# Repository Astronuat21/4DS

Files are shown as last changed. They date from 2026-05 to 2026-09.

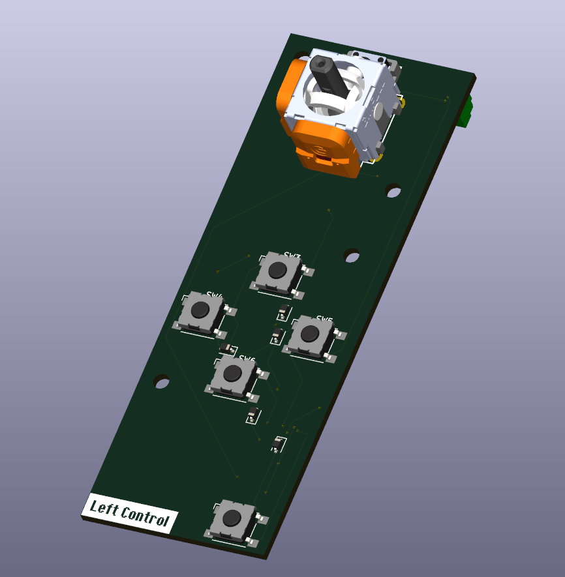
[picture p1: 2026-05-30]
Images/CTRL_L/Left_Controls_Front.png

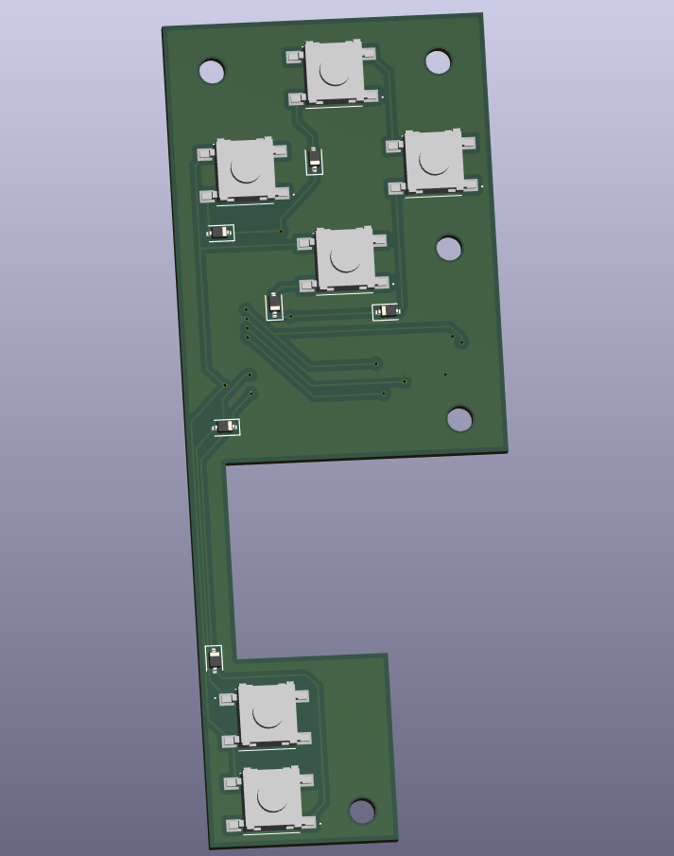
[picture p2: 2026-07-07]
Images/CTRL_R/Right_Controls_Front.png

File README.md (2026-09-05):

Hallo! Welcome to the Github Repository for the 4DS.

4DS is a solo project by Astronuat21 (me!!) aiming to make a dual screen console _akin to the Nintendo DS's_ but with stronger hardware, better battery life and specs in general. The device is also much larger than the ones you might have at home; coming in at around 19x11.5x3cm, the device is better suited for people with bigger hands who may find uncomfortability using even the stardard XL models. The hardware mostly tops the Switch, using the Lattepanda Mu SoC and it's N100 CPU, alongside 16GB of RAM and expandable Gen 3 SSD storage. If you so choose, this project should also be compatible with the upgraded N305 version (although it will be almost useless due to its higher PSU requirements).

This repository contains all the PCB files used in this project, including schematics and circuit boards. **Assuming everything works,** you should be able to reproduce the exact boards I used and reprint them for yourself. Also included are all the 3D files used in 3D printing or other purposes as well as some *outdated -_-* images to look at. They can be found in **/3D Models** and **/Images** respectively. You will also need some of the additional programs included for things like the RP2354 Microcontroller, alongside some other helpful scripts, which can be found in **/Programs**.

I built this to challenge myself to make a console that I would be proud to daily drive. My 2DS XL is great, but it definitely can't play my Steam library, and while I _can_ fit a Switch in some pockets, it dosen't quite have the extensive game library (for what I actually play). Unlike the _New (or not really)_ DS, which can play NES, SNES, GB/GBA, DS, and 3DS games as well as N64 and Gamecube to some extent. The Switch needs Nintendo Online for that as far as I know, and I HATE SUBSCRIPTIONS (Also its not even all the games). So thats where I've ended up now, with the great opportunity to flex superior intellect on some friends.

I may to make a sort of v2 version of this, there are quite a few fundemental issues with the design that cant really be fixed without starting over completely. I wouldn't really bother with that unless I find a way to make huge changes, like an insane side reduction, or adding a dGPU. I would probably make that a seperate repository, but it dosen't matter for now since I have other project ideas I want to do next.

If you intend to use this repository for any reason, **PLEASE CREDIT ME!!** I am happy to have others use this project as a reference or recreate what I have built, you can contact me with whatever you make, I would be honored. In the future, a _full-ish_ guide will be provided so that you can build your own 4DS if you'd like, but hopefully the repository is clear enough that you can do it on your own.

`DISCLAIMER: The 4DS and all its files is under the AGPL-3.0 license. I'm therefore technically allowing this repository to used for things like commercial purposes, but trust me, you really don't want to start using this repo just all on your own like that. My warning to you is that many decisions made here were done from extensive research and considerations from dozens of specifications and datasheets, some areas of this design are much more sensitive than expected, and some areas are not. I am happy to clarify certain things, but depending on what you hope to use this for, I may not give my time to help you if I do not support it. Dont expect me to help you out if your goal is to throw it with some AI Slop. I'm giving this warning not because you must consult me, but if you choose not to...`

**Find someone to wish you good luck. You're going to need it.**

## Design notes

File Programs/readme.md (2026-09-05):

Welcome to the _Programs_ Folder!

This folder is for programs, I guess. Not much to say for now since, I haven't done any coding yet!

also, isn't it interesting that github says my repo is like 91.7% Powershell? I wish it included stuff like kicad_ files, but I guess its not a programming language. whatevever -_-

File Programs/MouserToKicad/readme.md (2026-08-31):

Welcome to the _Programs_ Folder!

This folder is dedicated to a little powershell script I made *(sorry linux users)*. Its a basic utility that takes the zip folder download provided by Mouser (Or anything else that uses SamacSys, really) and puts it in an easier format to import with Kicad. 

To use it, you just have to input the name of the zip folder **(WITHOUT THE LIB_ PREFIX!)** and the script does the rest. Its not a perfect script though:

1. It assums the folder is in "D:\Downloads". You'll have to modify the $Downloads value to fit your needs. Windows comes with a PowerShell IDE, so you can change it via Right Click -> Edit
2. My Powershell is borked somehow and dosent like to run the .ps1 files properly. Ive thus included a .bat file that will run it properly, _just keep them in the same folder, aight?_

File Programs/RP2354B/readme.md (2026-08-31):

Welcome to the _Programs_ Folder!

This section is for configuration the RP2354B, the onboard microcontroller which handles USB Input, LED Peripherals, ADC Inputs and other I2C tasks. Further instructions will be given once the setup is finalized.

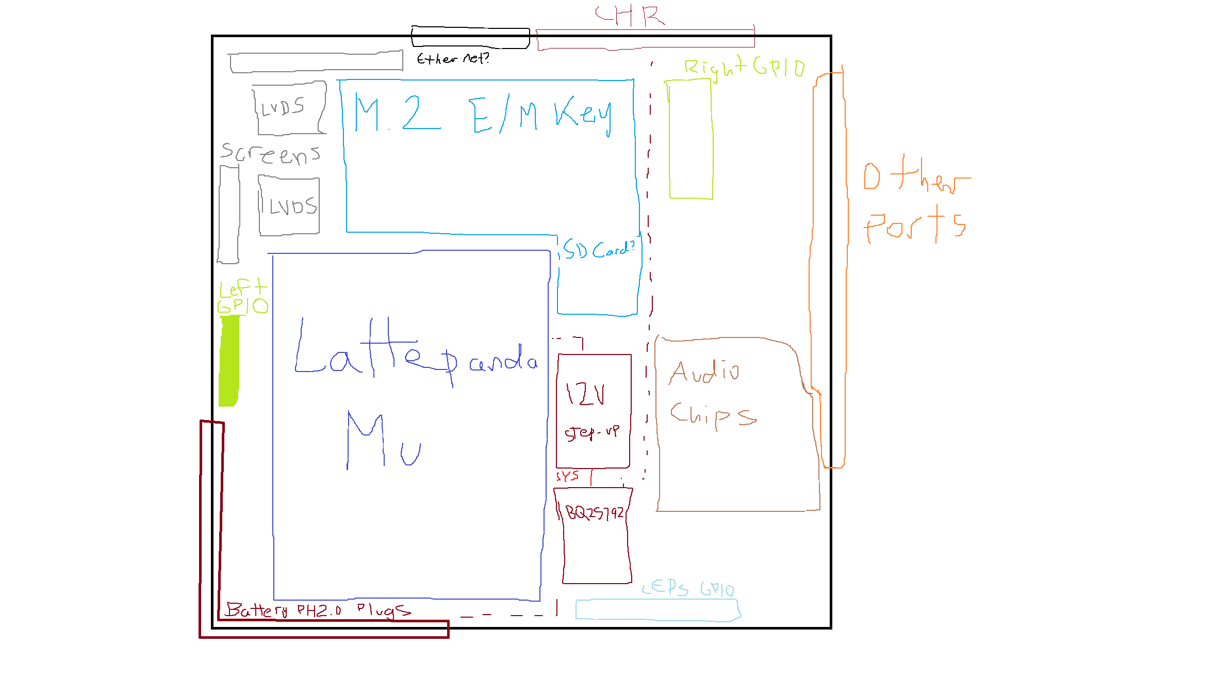
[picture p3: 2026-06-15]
Images/Motherboard/4DSMainboardConcept.png

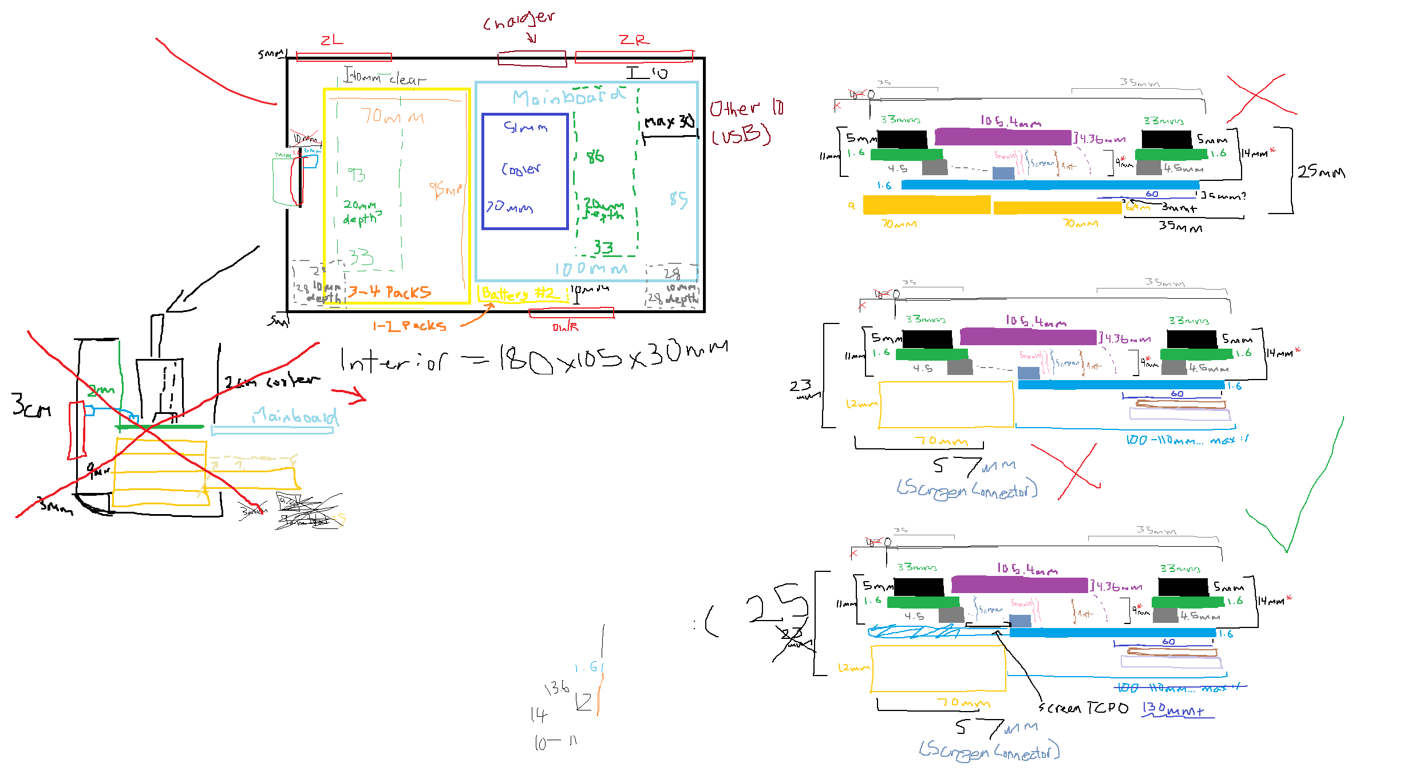
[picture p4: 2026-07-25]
Images/Other/4DS Concept Art.png

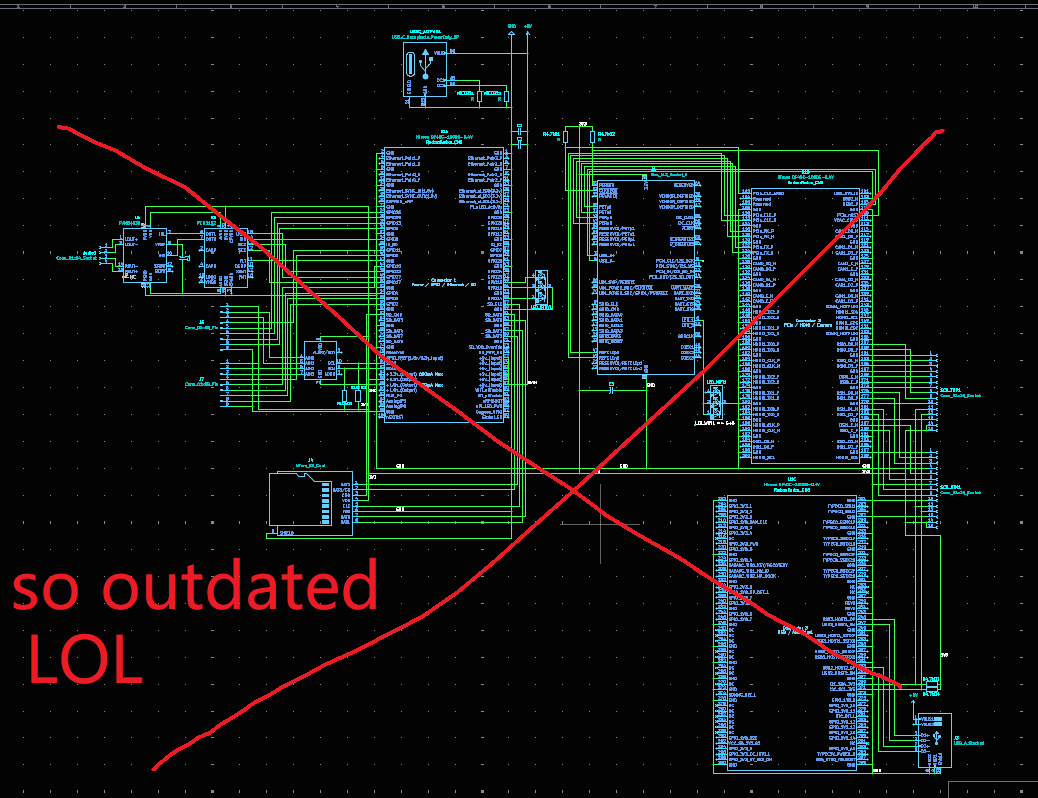
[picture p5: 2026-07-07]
Images/Motherboard/Schematic_05_11_26.png

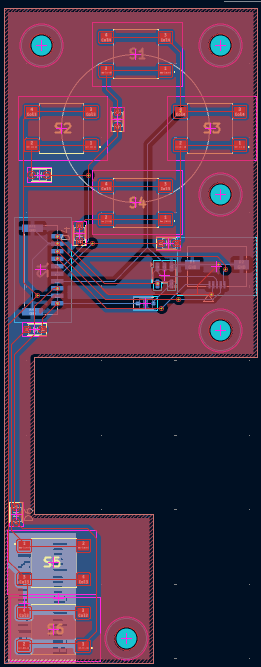
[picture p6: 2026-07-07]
Images/CTRL_R/Right_Controls_PCB.png

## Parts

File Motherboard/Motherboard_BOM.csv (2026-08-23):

Reference | Value | Footprint | Specifications (For Resistors/Capacitors) | MPN | Manufacturer
J78 | Speaker_L | Connector_Molex:Molex_PicoBlade_53047-0210_1x02_P1.25mm_Vertical | N/A | 0530470210
J79 | Speaker_R | Connector_Molex:Molex_PicoBlade_53047-0210_1x02_P1.25mm_Vertical | N/A | 0530470210
J24 | 200485-0710 | 2004850710 | N/A | 2004850710
J83 | 2004850740 | 200485-0740:CON_2004850740 | N/A | 2004850740
J90 | 2004850740 | CON_2004850740 | N/A | 2004850740
J91 | HDMI_A_1.4 | Connector_Video:HDMI_A_Molex_208658-1001_Horizontal | N/A | 2086581001
J52 | 503480-0800 | 503480-0800:5034800800 | N/A | 5034800800
J50,J51 | 5034801400 | 5034801400:5034801400 | N/A | 5034801400
L80,L83,L84 | 74438336010HT | 74438336010HT:74438336010HT | N/A | 74438336010HT
L85 | 74438336022HT | 74438336022HT:74438336022HT | N/A | 74438336022HT
F1 | 6V/50mA | Fuse:Fuse_0603_1608Metric | N/A | 0603L005/6AR
TH78 | 10k/1% | A_HDJ_Library:R_0603_1608Metric | N/A | 103AT-2
D4,D5,D6,D17,D34 | 1N5819WS | A_HDJ_Library:D_SOD-323 | N/A | 1N5819WS
Q80,Q81 | 2N7002 | Package_TO_SOT_SMD:SOT-23 | N/A | 2N7002
Y1,Y2 | ABM8-272-T3 | Crystal:Crystal_SMD_3225-4Pin_3.2x2.5mm | N/A | ABM8-272-T3
Y81,Y82 | Crystal_GND24 | A_HDJ_Library:Crystal_SMD_3225-4Pin_3.2x2.5mm | N/A | ABM8-28.63636MHZ-B2-T
A2 | LattePanda_Mu | Module_LattePanda:LattePanda_Module_H8.0mm_Horizontal |  | ADDR0207-P001A | LOTES
U96,U99 | ADV7611 | Package_QFP:LQFP-64-1EP_10x10mm_P0.5mm_EP5x5mm | N/A | ADV7611BSWZ-P-RL
C3,C4 | 15pF | Capacitor_SMD:C_0402_1005Metric | 15pF 0402 Ceramic 20% 16V X5R | any/open | any/open
C8,C9,C12,C13,C14,C15,C16,C17,C18,C20,C21 | 100nF | Capacitor_SMD:C_0402_1005Metric | 100nF 0402 Ceramic 20% 10V X5R | any/open | any/open
C10,C11,C19,C22 | 4.7uF | Capacitor_SMD:C_0402_1005Metric | 4.7uF 0402 Ceramic 20% 10V X5R | any/open | any/open
C25,C26,C27,C30,C31,C52,C54,C58,C60 | 100nF/50V | A_HDJ_Library:C_0402_1005Metric | 100nF 0402 Ceramic 20% 50V X5R | any/open | any/open
C49,C50,C55,C56 | 220nF/50V | A_HDJ_Library:C_0402_1005Metric | 220nF 0402 Ceramic 20% 50V X5R | any/open | any/open
C51,C53,C57,C59,C90,C110,C111,C112,C113,C114,C115,C116,C117,C121,C122,C123,C124,C125,C126,C127,C128,C129,C130,C140,C141,C142,C144,C145 | 10uF/10V | A_HDJ_Library:C_0402_1005Metric | 10uF 0402 Ceramic 20% 10V X5R | any/open | any/open
C61,C66 | 1uF/16V | A_HDJ_Library:C_0402_1005Metric | 1uF 0402 Ceramic 20% 16V X5R | any/open | any/open
C63,C86 | 22uF/10V | A_HDJ_Library:C_0603_1608Metric | 22uF 0603 Ceramic 20% 10V X5R | any/open | any/open
C87 | 1nF/50V | A_HDJ_Library:C_0402_1005Metric | 1nF 0402 Ceramic 10% 50V X5R | any/open | any/open
C92 | 0.1uF/25V | A_HDJ_Library:C_0603_1608Metric | 0.1uF 0603 Ceramic 20% 25V X5R | any/open | any/open
C93,C97 | 47nF/10V | A_HDJ_Library:C_0603_1608Metric | 47nF 0603 Ceramic 10% 10V X5R | any/open | any/open
C94 | 4.7uF/10V | A_HDJ_Library:C_0603_1608Metric | 4.7uF 0603 Ceramic 20% 10V X5R | any/open | any/open
C96,C153 | 10uF/10V | A_HDJ_Library:C_0603_1608Metric | 10uF 0603 Ceramic 20% 10V X5R | any/open | any/open
C100,C105,C133,C134,C135 | 10uF/25V | A_HDJ_Library:C_0603_1608Metric | 10uF 0603 Ceramic 20% 25V X5R | any/open | any/open
C101,C106 | 10uF | A_HDJ_Library:C_0603_1608Metric | 10uF 0603 Ceramic 20% 6.3V X5R | any/open | any/open
C107 | 10uF | Capacitor_SMD:C_0805_2012Metric | 10uF 0805 Ceramic 20% 16V X5R | any/open | any/open
C118,C146 | 100uF | A_HDJ_Library:C_0603_1608Metric | 100uF 0603 Ceramic 20% 10V X5R | any/open | any/open
C119,C120,C137,C147,C148,C151 | 1uF | A_HDJ_Library:C_0603_1608Metric | 1uF 0603 Ceramic 20% 10V X5R | any/open | any/open
C138 | 0.47uF | A_HDJ_Library:C_0603_1608Metric | 0.47uF 0603 Ceramic 20% 10V X5R | any/open | any/open
C150 | 10uF | A_HDJ_Library:C_0603_1608Metric | 10uF 0603 Ceramic 20% 10V X5R | any/open | any/open
C152 | 2.2uF/25V | A_HDJ_Library:C_0603_1608Metric | 2.2uF 0603 Ceramic 10% 25V X5R | any/open | any/open
C159 | 0.1uF | A_HDJ_Library:C_0603_1608Metric | 0.1uF 0603 Ceramic 20% 25V X5R | any/open | any/open
C160,C161 | 0.022uF | A_HDJ_Library:C_0603_1608Metric | 0.022uF 0603 Ceramic 20% 10V X5R | any/open | any/open
C164,C177 | 10uF | A_HDJ_Library:C_0402_1005Metric | 10uF 0402 Ceramic 20% 10V X5R | any/open | any/open
C165,C166,C176,C179 | 1uF | A_HDJ_Library:C_0402_1005Metric | 1uF 0402 Ceramic 20% 10V X5R | any/open | any/open
C167,C168,C183 | 1.2nF | A_HDJ_Library:C_0402_1005Metric | 1.2nF 0402 Ceramic 20% 50V X7R | any/open | any/open
C169 | 220nF | A_HDJ_Library:C_0402_1005Metric | 220nF 0402 Ceramic 20% 10V X5R | any/open | any/open
C170 | 10uF | A_HDJ_Library:C_0402_1005Metric | 10nF 0402 Ceramic 20% 6.3V X5R | any/open | any/open
C171 | 100nF | A_HDJ_Library:C_0603_1608Metric | 100nF 0603 Ceramic 20% 6.3V X7R | any/open | any/open
C172 | 2.2uF | A_HDJ_Library:C_0603_1608Metric | 2.2uF 0603 Ceramic 20% 10V X7R | any/open | any/open
C173 | 39nF | A_HDJ_Library:C_0402_1005Metric | 39nF 0402 Ceramic 20% 10V X5R | any/open | any/open
C174 | 91pF | A_HDJ_Library:C_0402_1005Metric | 91pF 0402 Ceramic 20% 50V C0G/NP0 | any/open | any/open
C175,C178 | 10nF | A_HDJ_Library:C_0402_1005Metric | 10nF 0402 Ceramic 20% 16V X5R | any/open | any/open
C180,C181,C182 | 47uF | Capacitor_SMD:C_0805_2012Metric | 47uF 0805 Ceramic 20% 16V X7R | any/open | any/open
R3,R12,R13,R16,R37,R47 | 1K/1% | A_HDJ_Library:R_0402_1005Metric | 1k 1% 63mW 0402 | any/open
R4,R18,R19,R20,R21,R34,R35,R36,R49,R92,R100,R101,R109,R110,R111,R115 | 10K/1% | A_HDJ_Library:R_0402_1005Metric | 10k 1% 63mW 0402 | any/open
R14,R15 | 27R | A_HDJ_Library:R_0402_1005Metric | 27R 1% 63mW 0402 | any/open
R17 | 33R/1% | A_HDJ_Library:R_0402_1005Metric | 33R 1% 63mW 0402 | any/open
R27,R29,R32,R33,R165,R180,R195 | 0R/1% | A_HDJ_Library:R_0402_1005Metric | 0R 1% 0402 | any/open
R30,R52,R53,R170,R185,R200 | 2.2K/1% | A_HDJ_Library:R_0402_1005Metric | 2.2k 1% 63mW 0402 | any/open
R43 | 6.8K/1% | A_HDJ_Library:R_0402_1005Metric | 6.8k 1% 63mW 0402 | any/open
R46,R48 | 100R/1% | A_HDJ_Library:R_0402_1005Metric | 100R 1% 63mW 0402 | any/open
R51,R80,R134,R138,R144 | 100K/1% | A_HDJ_Library:R_0402_1005Metric | 100k 1% 63mW 0402 | any/open
R76 | 100R/1% | Resistor_SMD:R_1206_3216Metric | 100R 1% 250mW 1206 | any/open
R77 | 4.7K/1% | A_HDJ_Library:R_0402_1005Metric | 4.7k 1% 63mW 0402 | any/open
R81,R82,R83,R164,R174,R177,R178,R179,R189,R192,R193,R194,R204,R207,R208 | 21.5K/1% | A_HDJ_Library:R_0402_1005Metric | 21.5k 1% 63mW 0402 | any/open
R84,R119 | 150R/1% | Resistor_SMD:R_0402_1005Metric | 150R 1% 63mW 0402 | any/open
R85,R86 | 10K/1% | Resistor_SMD:R_0402_1005Metric | 10k 1% 63mW 0402 | any/open
R89,R90 | 5.1K/1% | A_HDJ_Library:R_0402_1005Metric | 5.1k 1% 63mW 0402 | any/open
R91 | 10K/1% | A_HDJ_Library:R_0603_1608Metric | 10k 1% 100mW 0603 | any/open
R93 | 0.010R/1% | Resistor_SMD:R_2512_6332Metric | 0.01R 1% 3W 2512 | any/open
R94,R95 | 22R/1% | A_HDJ_Library:R_0603_1608Metric | 22R 1% 100mW 0603 | any/open
R97,R98,R104 | 470R/1% | A_HDJ_Library:R_0402_1005Metric | 470R 1% 63mW 0402 | any/open
R102,R106 | 16R/1% | A_HDJ_Library:R_0805_2012Metric | 16R 1% 125mW 0805 | any/open
R103,R105 | 330R/1% | A_HDJ_Library:R_0805_2012Metric | 330R 1% 125mW 0805 | any/open
R107 | 1.5k/1% | A_HDJ_Library:R_0805_2012Metric | 1.5k 1% 125mW 0805 | any/open
R108 | 1M/1% | A_HDJ_Library:R_0603_1608Metric | 1M 1% 100mW 0603 | any/open
R112 | 2R/1% | A_HDJ_Library:R_0805_2012Metric | 2R 1% 125mW 0805 | any/open
R113,R114 | 127K/1% | A_HDJ_Library:R_0402_1005Metric | 127k 1% 63mW 0402 | any/open
R116 | 100k/1% | A_HDJ_Library:R_0402_1005Metric | 100k 1% 63mW 0402 | any/open
R117 | 5.24k/1% | A_HDJ_Library:R_0402_1005Metric | 5.24k 1% 63mW 0402 | any/open
R118 | 30k/1% | A_HDJ_Library:R_0402_1005Metric | 30k 1% 63mW 0402 | any/open
R120 | 5.1R/1% | A_HDJ_Library:R_0402_1005Metric | 5.1R 1% 63mW 0402 | any/open
R121,R122,R127,R128 | 910k/1% | A_HDJ_Library:R_0402_1005Metric | 910k 1% 63mW 0402 | any/open
R123,R126 | 5k/1% | A_HDJ_Library:R_0402_1005Metric | 5k 1% 63mW 0402 | any/open
R124,R125 | 90k/1% | A_HDJ_Library:R_0402_1005Metric | 90k 1% 63mW 0402 | any/open
R129 | 10R/1% | A_HDJ_Library:R_0402_1005Metric | 10R 1% 63mW 0402 | any/open
R130,R131,R132,R133 | 47R/1% | Resistor_SMD:R_0402_1005Metric | 47R 1% 63mW 0402 | any/open
R135 | 21K/1% | A_HDJ_Library:R_0402_1005Metric | 21k 1% 63mW 0402 | any/open
R139 | 249K/1% | A_HDJ_Library:R_0402_1005Metric | 249k 1% 63mW 0402 | any/open
R145 | 76.8k/1% | A_HDJ_Library:R_0402_1005Metric | 76.8k 1% 63mW 0402 | any/open
R166,R167,R168,R169,R172,R173,R175,R176,R181,R182,R183,R184,R187,R188,R190,R191,R196,R197,R198,R199,R202,R203,R205,R206 | 56K/1% | A_HDJ_Library:R_0402_1005Metric | 56k 1% 63mW 0402 | any/open
Q11,Q23,Q29 | AO3407 | Package_TO_SOT_SMD:SOT-23 | N/A | AO3407
L5 | 3.3uH | Inductor_SMD:L_0603_1608Metric | N/A | AOTA-B201610S3R3-101-T | ABRACON
J15 | Bus_M.2_Socket_M | A_HDJ_Library:PCIe_M.2_Connectors_P=0.5mm_H=4.2mm_KeyM | N/A | APCI0107-P001A | Lian Xin Technology
J16 | Bus_M.2_Socket_E | A_HDJ_Library:PCIe_M.2_Connectors_P=0.5mm_H=4.2mm_KeyE | N/A | APCI0108-P001A | Lian Xin Technology
J85 | JST_XHP2_Battery1 | Connector_JST:JST_XH_B2B-XH-A_1x02_P2.50mm_Vertical | N/A | B2B-XH-A
J86 | JST_XHP2_Battery2 | Connector_JST:JST_XH_B2B-XH-A_1x02_P2.50mm_Vertical | N/A | B2B-XH-A
J87 | JST_XHP2_Battery3 | Connector_JST:JST_XH_B2B-XH-A_1x02_P2.50mm_Vertical | N/A | B2B-XH-A
J88 | JST_XHP2_Battery4 | Connector_JST:JST_XH_B2B-XH-A_1x02_P2.50mm_Vertical | N/A | B2B-XH-A
J89 | JST_XHP2_Battery5 | Connector_JST:JST_XH_B2B-XH-A_1x02_P2.50mm_Vertical | N/A | B2B-XH-A
D24 | 3V3 Izt=5mA | A_HDJ_Library:D_SOD-323 | N/A | B5819WS-TP
SW80,SW81 | SW_Push | Button_Switch_SMD:SW_SPST_B3U-1000P | N/A | B3U-1000P
U79 | BQ25798 | Package_DFN_QFN:Texas_RQM0029A_VQFN-29_4x4mm_P0.4mm | N/A | BQ25798RQMR
U82 | BQ27441DRZT-G1A | Package_SON:Texas_S-PDSO-N12 | N/A | BQ27441DRZT-G1A
BT2 | Battery_Cell | A_HDJ_Library:Battery_Holder_CR1220_S8411-45R |  | BS-12-B3AA003 | MYOUNG
SW82 | SW_Nidec_CAS-120A1 | Button_Switch_SMD:Nidec_Copal_CAS-120A | N/A | CAS-120A
U14 | CH224K | A_HDJ_Library:ESSOP-10-1EP_3.9x5mm_P1.0mm_EP3.2x2.3 | N/A | CH224K
R136,R137,R140,R143 | 40.2K/1% | A_HDJ_Library:R_0402_1005Metric | 40.2k 1% 63mW 0402 | CRCW040240K2FKED | Vishay-Dale
R142 | 48.7k/1% | A_HDJ_Library:R_0402_1005Metric | 48.7k 1% 63mW 0402 | CRCW040248K7FKED
R141 | 681k/1% | A_HDJ_Library:R_0402_1005Metric | 681k 1% 63mW 0402 | CRCW0402681KFKED
U89,U90,U91,U92,U97,U98 | D3V3XA4B10LP | Package_DFN_QFN:Diodes_UDFN-10_1x2.5mm_P0.5mm | N/A | D3V3XA4B10LP-7
D7,D8,D10,D11,D15,D16,D21,D33 | ESD5V0B03 | A_HDJ_Library:D_0402_1005Metric | N/A | ESD5V0B03-1006
U3,U9,U12 | ULC0524P | A_HDJ_Library:Diodes_UDFN-10_1.0x2.5mm_P0.5mm | N/A | ESDULC0524P5-TP
J84 | FFC2A33-08-T-R | FFC2A33-08-T-R:FFC2A3308TR | N/A | FFC2A33-08-T-R
C154,C155,C156,C157 | 22uF/25V | Capacitor_SMD:C_1210_3225Metric | 22uF 1210 Ceramic 20% 25V X7R | GRM32ER61E226KE15L | any/open
J81,J94 | GSB311A41EU | GSB311A41EU:GSB311A41EU | N/A | GSB311A41EU
Q12,Q24,Q25,Q26,Q27,Q28,Q30,Q31,Q32 | HM7533HBPR | Package_TO_SOT_SMD:SOT-89-3 | N/A | HM7533HBPR
L87,L88 | LQH32CN220K23L | LQH32CN220K23L:LQH32DN100K23L | N/A | LQH32CN220K23L
C139,C143 | 22uF/4V | Capacitor_SMD:C_0805_2012Metric | 22uF 0805 Ceramic 20% 4V X5R | MCASA21GAB5226MTNA01 | any/open
C149 | 22uF | Capacitor_SMD:C_0805_2012Metric | 22uF 0805 Ceramic 20% 10V X5R | MCASA21GAB5226MTNA01 | any/open
TP2,TP10 | TestPoint | A_HDJ_Library:TestPoint_Pad_D1.5mm | N/A | N/A
U80,U85 | PAM2841G | Package_DFN_QFN:DFN-8-1EP_2x2mm_P0.5mm_EP0.86x1.55mm | N/A | PAM2841GR
U84 | PAM8403D | Package_SO:SOIC-16_3.9x9.9mm_P1.27mm | N/A | PAM8403DR-H
IC78 | PCM2704CDBR | PCM2704CDBR:SOP65P780X200-28N | N/A | PCM2704CDBR
D12,D13,D14 | PESD24VS1UL-N | A_HDJ_Library:D_0402_1005Metric | N/A | PESD24VS1UL-N
J5 | SM03B-SRSS-TB | Connector_JST:JST_SH_SM03B-SRSS-TB_1x03-1MP_P1.00mm_Horizontal | N/A | SM03B-SRSS-TB
U88 | RP2354B | Package_DFN_QFN:QFN-80-1EP_10x10mm_P0.4mm_EP3.4x3.4mm | N/A | SC1512-A4
F4,F6 | 6V/2A | A_HDJ_Library:Fuse_0805_2012Metric | N/A | SMD0805B110TF
H7,H8 | MountingHole_M2.0 | A_HDJ_Library:MountingHole_3mm_M2_Pad_TopOnly | N/A | SMTWEM225STR
H9,H10 | MountingHole_Pad | A_HDJ_Library:MountingHole_3mm_M2_Pad_TopOnly | N/A | SMTWEM225STR
D18,D19,D20,D23,D28,D29,D30 | SS54 | A_HDJ_Library:D_SMA | N/A | SS54
IC82 | TPS61288LRQQR | PTPS61288RQQR | N/A | TPS61288LRQQR
IC81,IC83,IC84 | TPS62903RPJR | TPS62903RPJR:TPS62903RPJR | N/A | TPS62903RPJR
IC79 | TS3DV621RUAR | QFN50P350X900X80-43N-D | N/A | TS3DV621RUAR
J80 | USB_C_Receptacle_USB2.0_16P | Connector_USB:USB_C_Receptacle_GCT_USB4105-xx-A_16P_TopMnt_Horizontal | N/A | USB4105-GF-A
L79 | XAL8080-222MEB | XAL8080-222MED:XAL8080222MED | N/A | XAL8080-222MEB
D9,D22 | LED_G | A_HDJ_Library:LED_0603_1608Metric | N/A | XL-1608UGC-04

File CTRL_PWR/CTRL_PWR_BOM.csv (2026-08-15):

Reference | Qty | Value | Footprint | MPN | Manufacturer
S1 | 1 | B3S-1002 | B3S-1002:B3S1002 | B3S-1002 | OMRON
J2 | 1 | 503480-0800 | 503480-0800:5034800800 | 5034800800 | MOLEX
D3,D4 | 2 | LED_RKGB | LED_THT:LED_D5.0mm-4_RGB | TJ-L5FCMXHTCSLCRGB-A5 | TOGIALED

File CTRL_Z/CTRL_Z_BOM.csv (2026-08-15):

Reference | Qty | Value | Footprint | MPN | Manufacturer
D22,D23,D24,D25 | 4 | ESD5V0B03 | A_HDJ_Library:D_0402_1005Metric | ESD5V0B03-1006 | TECH PUBLIC
J2 | 1 | 503480-0440 | 503480-0440:5034800440 | 5034800440 | MOLEX
S1,S2 | 2 | B3S-1002 | B3S-1002:B3S1002 | B3S-1002 | OMRON

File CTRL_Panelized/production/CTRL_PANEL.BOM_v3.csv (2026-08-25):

Designator | Footprint | Quantity | Value | MPN | Manufacturer
D10, D15, D17, D18, D22, D23, D25, D27, D29, D31, D33, D37, D38 | D_SOD-323 | 13 | 1N4148WS | 1N4148WS | JSMSEMI
D1, D11, D12, D13, D14, D16, D19, D20, D21, D24, D26, D28, D30, D32, D34, D35, D36, D39, D4, D40, D5, D6, D7, D8, D9 | 0402 | 25 | ESD5V0B03 | ESD5V0B03-1006 | TECH PUBLIC
D2, D3 | LED_D5.0mm-4_RGB | 2 | LED_RKGB | TJ-L5FCMXHTCSLCRGB-A5 | TOGIALED
J7, J9 | 5034800540 | 2 | 503480-0540 | 5034800540 | MOLEX
J10, J8 | 5034801400 | 2 | 5034801400 | 5034801400 | MOLEX
J2, J3, J4, J5, J6, J11 | 5034800440 | 4 | 503480-0440 | 5034800440 | MOLEX
J1 | 5034800800 | 1 | 503480-0800 | 5034800800 | MOLEX
S1, S2, S3, S5, S8 | B3S1002 | 5 | B3S-1002 | B3S-1002 | OMRON
S10, S11, S12, S13, S14, S15, S16, S4, S6, S7, S9 | B3S1000 | 11 | B3S-1000 | B3S-1000 | OMRON
U1, U4 | SOT-23-5 | 2 | 74LVC1G08 | 74LVC1G08GV | MDD(Microdiode Semiconductor)
U2, U3 | SOT-23 | 2 | DRV5033FAxDBZ | DRV5033FAQDBZR | TI

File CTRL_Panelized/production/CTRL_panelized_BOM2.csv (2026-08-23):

Id | Designator | Footprint | Quantity | Designation | Supplier and ref
1 | D1, D4, D5, D6, D7, D8, D9, D11, D12, D13, D14, D16, D19, D20, D21, D24, D26, D28, D30, D32, D34, D35, D36, D39, D40 | D_0402_1005Metric | 25 | ESD5V0B03
2 | D2, D3 | LED_D5.0mm-4_RGB | 2 | LED_RKGB
3 | D10, D15, D17, D18, D22, D23, D25, D27, D29, D31, D33, D37, D38 | D_SOD-323 | 13 | 1N4148WS
4 | J1 | 5034800800 | 1 | 503480-0800
5 | J2, J3, J4, J6 | 5034800440 | 4 | 503480-0440
6 | J5, J11 | AYF530365T | 2 | AYF530365TA
7 | J7, J9 | 5034800540 | 2 | 503480-0540
8 | J8, J10 | 5034801400 | 2 | 5034801400
9 | S1, S2, S3, S5, S8 | B3S1002 | 5 | B3S-1002
10 | S4, S6, S7, S9, S10, S11, S12, S13, S14, S15, S16 | B3S1000 | 11 | B3S-1000
11 | U1, U4 | SOT-23 | 2 | DRV5033FAxDBZ
12 | U2, U3 | SOT-23-5 | 2 | 74LVC1G08

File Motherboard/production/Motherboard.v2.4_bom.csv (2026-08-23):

Designator | Footprint | Quantity | Value | LCSC Part #
A2 | LattePanda_Module_H8.0mm_Horizontal | 1 | LattePanda_Mu | ADDR0207-P001A
BT2 | Battery_Holder_CR1220_S8411-45R | 1 | Battery_Cell | BS-12-B3AA003
C10, C11, C19, C22 | 0402 | 4 | 4.7uF | any/open
C100, C105, C133, C134, C135 | 0603 | 5 | 10uF/25V | any/open
C101, C106, C150 | 0603 | 3 | 10uF | any/open
C107 | 0805 | 1 | 10uF | any/open
C110, C111, C112, C113, C114, C115, C116, C117, C121, C122, C123, C124, C125, C126, C127, C128, C129, C130, C140, C141, C142, C144, C145, C51, C53, C57, C59, C90 | 0402 | 28 | 10uF/10V | any/open
C118, C146 | 1210 | 2 | 100uF | any/open
C119, C120, C137, C147, C148, C151 | 0603 | 6 | 1uF | any/open
C12, C13, C14, C15, C16, C17, C18, C20, C21, C8, C9 | 0402 | 11 | 100nF | any/open
C138 | 0603 | 1 | 0.47uF | any/open
C139, C143 | 0805 | 2 | 22uF/4V | MCASA21GAB5226MTNA01
C149 | 0805 | 1 | 22uF | MCASA21GAB5226MTNA01
C152 | 0603 | 1 | 2.2uF/25V | any/open
C153, C96 | 0603 | 2 | 10uF/10V | any/open
C154, C155, C156, C157 | 1210 | 4 | 22uF/25V | GRM32ER61E226KE15L
C159 | 0603 | 1 | 0.1uF | any/open
C160, C161 | 0603 | 2 | 0.022uF | any/open
C164, C170, C177 | 0402 | 3 | 10uF | any/open
C165, C166, C176, C179 | 0402 | 4 | 1uF | any/open
C167, C168, C183 | 0402 | 3 | 1.2nF | any/open
C169 | 0402 | 1 | 220nF | any/open
C171 | 0603 | 1 | 100nF | any/open
C172 | 0603 | 1 | 2.2uF | any/open
C173 | 0402 | 1 | 39nF | any/open
C174 | 0402 | 1 | 91pF | any/open
C175, C178 | 0402 | 2 | 10nF | any/open
C180, C181, C182 | 1210 | 3 | 47uF | any/open
C25, C26, C27, C30, C31, C52, C54, C58, C60 | 0402 | 9 | 100nF/50V | any/open
C3, C4 | 0603 | 2 | 15pF | C0603C150K4RACTU
C49, C50, C55, C56 | 0402 | 4 | 220nF/50V | any/open
C61, C66 | 0402 | 2 | 1uF/16V | any/open
C63, C86 | 0603 | 2 | 22uF/10V | any/open
C87 | 0402 | 1 | 1nF/50V | any/open
C92 | 0603 | 1 | 0.1uF/25V | any/open
C93, C97 | 0603 | 2 | 47nF/10V | any/open
C94 | 0603 | 1 | 4.7uF/10V | any/open
D10, D11, D15, D16, D21, D33, D7, D8 | 0402 | 8 | ESD5V0B03 | ESD5V0B03-1006
D12, D13, D14 | 0402 | 3 | PESD24VS1UL-N | PESD24VS1UL-N
D17, D34, D4, D5, D6 | D_SOD-323 | 5 | 1N5819WS | 1N5819WS
D18, D19, D20, D23, D28, D29, D30 | D_SMA | 7 | SS54 | SS54
D22, D9 | 0603 | 2 | LED_G | XL-1608UGC-04
D24 | D_SOD-323 | 1 | 3V3 Izt=5mA | B5819WS-TP
F1 | 0603 | 1 | 6V/50mA | 0603L005/6AR
F4, F6 | 0805 | 2 | 6V/2A | SMD0805B110TF
H10, H9 | MountingHole_3mm_M2_Pad_TopOnly | 2 | MountingHole_Pad | SMTWEM225STR
H7, H8 | MountingHole_3mm_M2_Pad_TopOnly | 2 | MountingHole_M2.0 | SMTWEM225STR
IC78 | SOP65P780X200-28N | 1 | PCM2704CDBR | PCM2704CDBR
IC79 | QFN50P350X900X80-43N-D | 1 | TS3DV621RUAR | TS3DV621RUAR
IC81, IC83, IC84 | TPS62903RPJR | 3 | TPS62903RPJR | TPS62903RPJR
IC82 | PTPS61288RQQR | 1 | TPS61288LRQQR | TPS61288LRQQR
J15 | PCIe_M.2_Connectors_P=0.5mm_H=4.2mm_KeyM | 1 | Bus_M.2_Socket_M | APCI0107-P001A
J16 | PCIe_M.2_Connectors_P=0.5mm_H=4.2mm_KeyE | 1 | Bus_M.2_Socket_E | APCI0108-P001A
J24 | 2004850710 | 1 | 200485-0710 | 2004850710
J5 | JST_SH_SM03B-SRSS-TB_1x03-1MP_P1.00mm_Horizontal | 1 | SM03B-SRSS-TB | SM03B-SRSS-TB
J50, J51 | 5034801400 | 2 | 5034801400 | 5034801400
J52 | 5034800800 | 1 | 503480-0800 | 5034800800
J78 | Molex_PicoBlade_53047-0210_1x02_P1.25mm_Vertical | 1 | Speaker_L | 0530470210
J79 | Molex_PicoBlade_53047-0210_1x02_P1.25mm_Vertical | 1 | Speaker_R | 0530470210
J80 | USB_C_Receptacle_GCT_USB4105-xx-A_16P_TopMnt_Horizontal | 1 | USB_C_Receptacle_USB2.0_16P | USB4105-GF-A
J81, J94 | GSB311A41EU | 2 | GSB311A41EU | GSB311A41EU
J83, J90 | CON_2004850740 | 2 | 2004850740 | 2004850740
J84 | FFC2A3308TR | 1 | FFC2A33-08-T-R | FFC2A33-08-T-R
J85 | JST_XH_B2B-XH-A_1x02_P2.50mm_Vertical | 1 | JST_XHP2_Battery1 | B2B-XH-A
J86 | JST_XH_B2B-XH-A_1x02_P2.50mm_Vertical | 1 | JST_XHP2_Battery2 | B2B-XH-A
J87 | JST_XH_B2B-XH-A_1x02_P2.50mm_Vertical | 1 | JST_XHP2_Battery3 | B2B-XH-A
J88 | JST_XH_B2B-XH-A_1x02_P2.50mm_Vertical | 1 | JST_XHP2_Battery4 | B2B-XH-A
J89 | JST_XH_B2B-XH-A_1x02_P2.50mm_Vertical | 1 | JST_XHP2_Battery5 | B2B-XH-A
J91 | HDMI_A_Molex_208658-1001_Horizontal | 1 | HDMI_A_1.4 | 2086581001
L5 | L_pol_2016 | 1 | 3.3uH | AOTA-B201610S3R3-101-T
L79 | XAL8080222MED | 1 | XAL8080-222MEB | XAL8080-222MEB
L80, L83, L84 | 74438336010HT | 3 | 74438336010HT | 74438336010HT
L85 | 74438336022HT | 1 | 74438336022HT | 74438336022HT
L87, L88 | LQH32DN100K23L | 2 | LQH32CN220K23L | LQH32CN220K23L
Q11, Q23, Q29 | SOT-23 | 3 | AO3407 | AO3407
Q12, Q24, Q25, Q26, Q27, Q28, Q30, Q31, Q32 | SOT-89-3 | 9 | HM7533HBPR | HM7533HBPR
Q80, Q81 | SOT-23 | 2 | 2N7002 | 2N7002
R100, R101, R109, R110, R111, R115, R18, R19, R20, R21, R34, R35, R36, R4, R49, R85, R86, R92 | 0402 | 18 | 10K/1% | any/open
R102, R106 | 0805 | 2 | 16R/1% | any/open
R103, R105 | 0805 | 2 | 330R/1% | any/open
R104, R97, R98 | 0402 | 3 | 470R/1% | any/open
R107 | 0805 | 1 | 1.5k/1% | any/open
R108 | 0603 | 1 | 1M/1% | any/open
R112 | 0805 | 1 | 2R/1% | any/open
R113, R114 | 0402 | 2 | 127K/1% | any/open
R116, R134, R138, R144, R51, R80 | 0402 | 6 | 100k/1% | any/open
R117 | 0402 | 1 | 5.24k/1% | any/open
R118 | 0402 | 1 | 30k/1% | any/open
R119, R84 | 0402 | 2 | 150R/1% | any/open
R12, R13, R16, R3, R37, R47 | 0402 | 6 | 1K/1% | any/open
R120 | 0402 | 1 | 5.1R/1% | any/open
R121, R122, R127, R128 | 0402 | 4 | 910k/1% | any/open
R123, R126 | 0402 | 2 | 5k/1% | any/open
R124, R125 | 0805 | 2 | 90k/1% | any/open
R129 | 0402 | 1 | 10R/1% | any/open
R130, R131, R132, R133 | 0402 | 4 | 47R/1% | any/open
R135 | 0402 | 1 | 21K/1% | any/open
R136, R137, R140, R143 | 0402 | 4 | 40.2K/1% | CRCW040240K2FKED
R139 | 0402 | 1 | 249K/1% | any/open
R14, R15 | 0402 | 2 | 27R | any/open
R141 | 0402 | 1 | 681k/1% | CRCW0402681KFKED
R142 | 0402 | 1 | 48.7k/1% | CRCW040248K7FKED
R145 | 0402 | 1 | 76.8k/1% | any/open
R164, R174, R177, R178, R179, R189, R192, R193, R194, R204, R207, R208, R81, R82, R83 | 0402 | 15 | 21.5K/1% | any/open
R165, R180, R195, R27, R29, R32, R33 | 0402 | 7 | 0R/1% | any/open
R166, R167, R168, R169, R172, R173, R175, R176, R181, R182, R183, R184, R187, R188, R190, R191, R196, R197, R198, R199, R202, R203, R205, R206 | 0402 | 24 | 56K/1% | any/open
R17 | 0402 | 1 | 33R/1% | any/open
R170, R185, R200, R30, R52, R53 | 0402 | 6 | 2.2K/1% | any/open
R43 | 0402 | 1 | 6.8K/1% | any/open
R46, R48 | 0402 | 2 | 100R/1% | any/open
R76 | 1206 | 1 | 100R/1% | any/open
R77 | 0402 | 1 | 4.7K/1% | any/open
R89, R90 | 0402 | 2 | 5.1K/1% | any/open
R91 | 0603 | 1 | 10K/1% | any/open
R93 | 2512 | 1 | 0.010R/1% | any/open
R94, R95 | 0603 | 2 | 22R/1% | any/open
SW80, SW81 | SW_SPST_B3U-1000P | 2 | SW_Push | B3U-1000P
SW82 | Nidec_Copal_CAS-120A | 1 | SW_Nidec_CAS-120A1 | CAS-120A
TH78 | 0603 | 1 | 10k/1% | 103AT-2
TP10, TP2 | TestPoint_Pad_D1.5mm | 2 | TestPoint | N/A
U12, U3, U9 | Diodes_UDFN-10_1.0x2.5mm_P0.5mm | 3 | ULC0524P | ESDULC0524P5-TP
U14 | ESSOP-10-1EP_3.9x5mm_P1.0mm_EP3.2x2.3 | 1 | CH224K | CH224K
U79 | Texas_RQM0029A_VQFN-29_4x4mm_P0.4mm | 1 | BQ25798 | BQ25798RQMR
U80, U85 | DFN-8-1EP_2x2mm_P0.5mm_EP0.86x1.55mm | 2 | PAM2841G | PAM2841GR
U82 | Texas_S-PDSO-N12 | 1 | BQ27441DRZT-G1A | BQ27441DRZT-G1A
U84 | SOIC-16_3.9x9.9mm_P1.27mm | 1 | PAM8403D | PAM8403DR-H
U88 | QFN-80-1EP_10x10mm_P0.4mm_EP3.4x3.4mm | 1 | RP2354B | SC1512-A4
U89, U90, U91, U92, U97, U98 | Diodes_UDFN-10_1x2.5mm_P0.5mm | 6 | D3V3XA4B10LP | D3V3XA4B10LP-7
U96, U99 | LQFP-64-1EP_10x10mm_P0.5mm_EP5x5mm | 2 | ADV7611 | ADV7611BSWZ-P-RL
Y1, Y2 | Crystal_SMD_3225-4Pin_3.2x2.5mm | 2 | ABM8-272-T3 | ABM8-272-T3
Y81, Y82 | Crystal_SMD_3225-4Pin_3.2x2.5mm | 2 | Crystal_GND24 | ABM8-28.63636MHZ-B2-T

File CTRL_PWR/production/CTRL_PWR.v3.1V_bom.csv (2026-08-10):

Designator | Footprint | Quantity | Value | LCSC Part #
D3, D4 | LED_D5.0mm-4_RGB | 2 | LED_RKGB | C2837020
J2 | 5034800800 | 1 | 503480-0800 | C596711
S1 | B3S1002 | 1 | B3S-1002 | C2733654

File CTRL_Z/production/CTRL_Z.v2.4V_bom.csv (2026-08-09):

Designator | Footprint | Quantity | Value | LCSC Part #
D22, D23, D24, D25 | 0402 | 4 | ESD5V0B03 | C521894
J2 | 5034800440 | 1 | 503480-0440 | C3170007
S1, S2 | B3S1002 | 2 | B3S-1002 | C2733654

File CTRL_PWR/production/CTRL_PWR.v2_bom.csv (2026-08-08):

Designator | Footprint | Quantity | Value | LCSC Part #
D21 | 0402 | 1 | ESD5V0B03 | C521894
D3, D4 | LED_D5.0mm-4_RGB | 2 | LED_RKGB | C2837020
J2 | 5034800800 | 1 | 503480-0800 | C596711
R1, R2 | 0402 | 2 | 180R
R3, R4, R5, R6 | 0402 | 4 | 47R
S1 | B3S1002 | 1 | B3S-1002 | C2733654

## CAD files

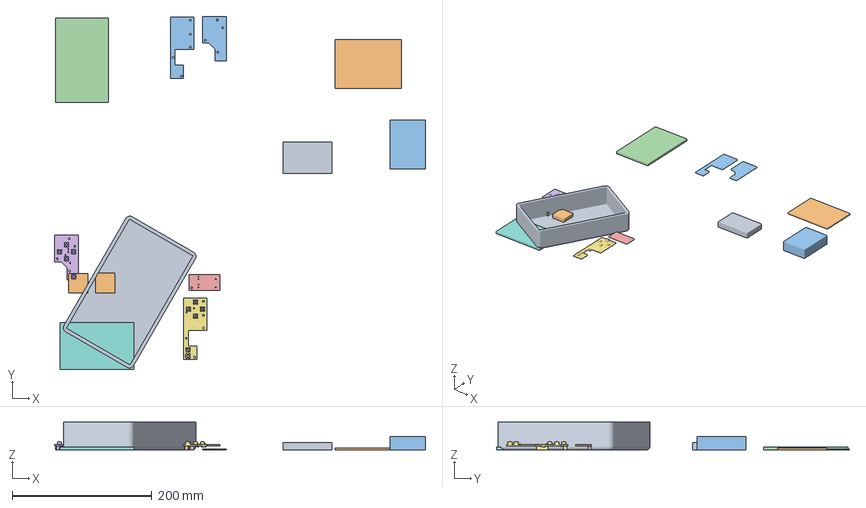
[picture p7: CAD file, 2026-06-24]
3D Models/General/3W_Speakers.3mf
530.3 x 504.5 x 40.0 mm
LattePandaCoolerMiniPassive.stl
Battery307095.stl
LattePandaCoolerFan.stl
TopScreen.stl
CTRL_L_SLIDERS_JUN11.stl
CTRL_L_JUN11.stl
CTRL_R_JUN11.stl
BottomScreen.stl
4DS Shell test 180x105x40, +5S F=7 B=5.obj
Assembly x 2

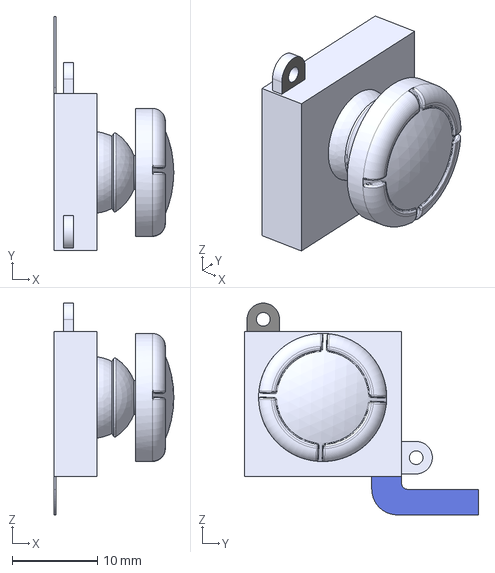
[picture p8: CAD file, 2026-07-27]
3D Models/General/switch-joycon-joystick-1.snapshot.6/Switch JoyCon joystick v2.step
14.0 x 27.4 x 24.8 mm

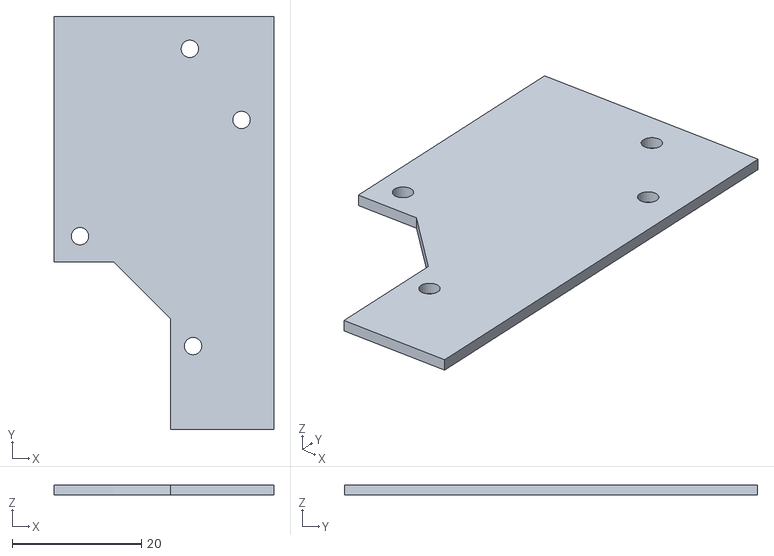
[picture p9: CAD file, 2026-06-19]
3D Models/ShellTest/CTRL_L_UNP.stl
34.0 x 63.9 x 1.51

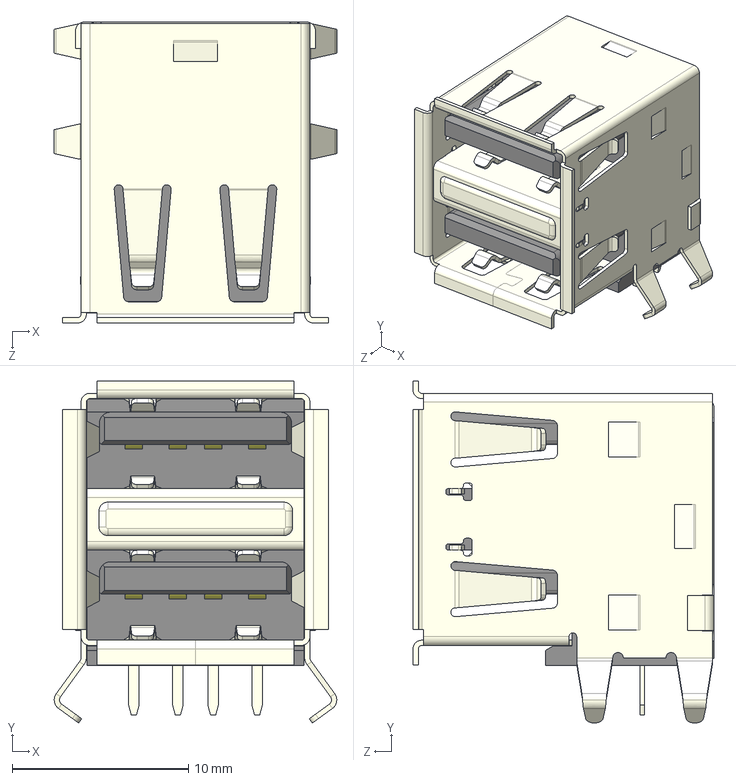
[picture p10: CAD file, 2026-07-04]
Motherboard/3D_models/Same_Sky_UJ2-ADH-3-TH.step
16.0 x 19.4 x 17.1 mm

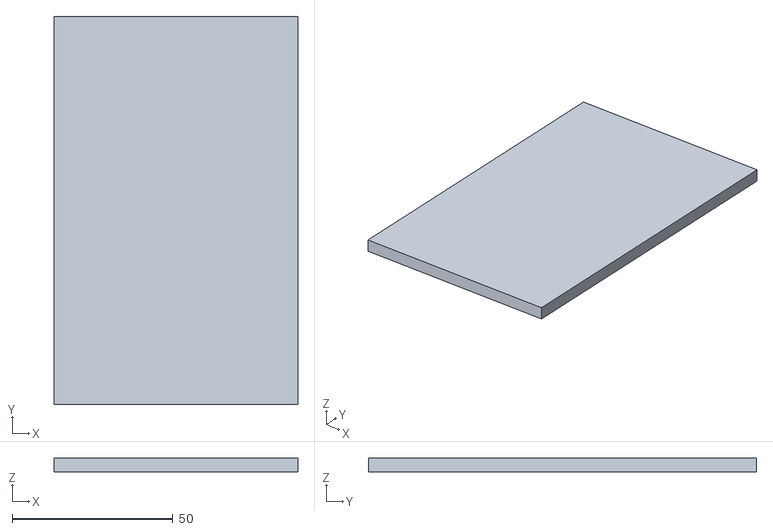
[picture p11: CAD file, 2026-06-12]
3D Models/General/TopScreen.stl
75.9 x 120.7 x 4.48

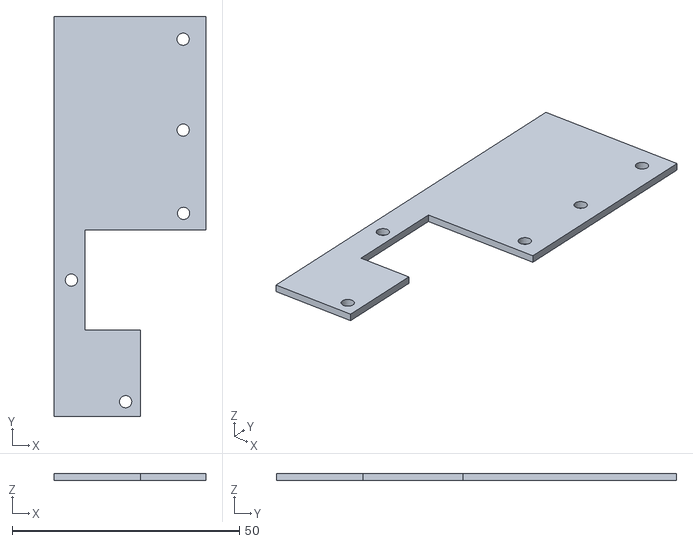
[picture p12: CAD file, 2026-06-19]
3D Models/ShellTest/CTRL_R_UNP.stl
33.4 x 88.0 x 1.51

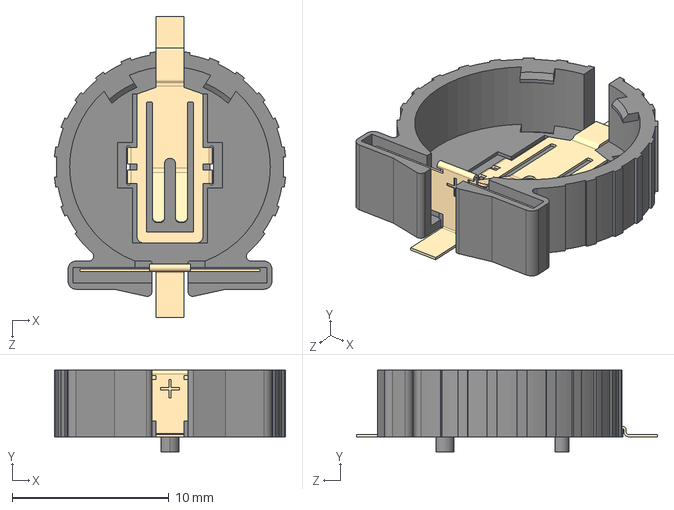
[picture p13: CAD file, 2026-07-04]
Motherboard/3D_models/S8411-45R.step
14.7 x 5.20 x 19.2 mm

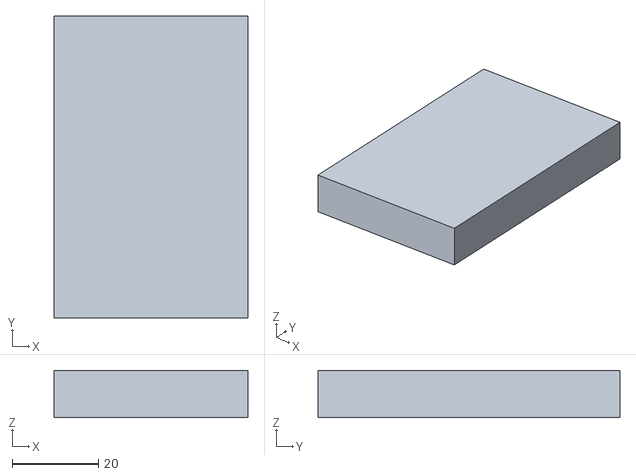
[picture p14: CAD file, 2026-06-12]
3D Models/General/LattePandaCoolerMiniPassive.stl
45.0 x 70.0 x 11.0

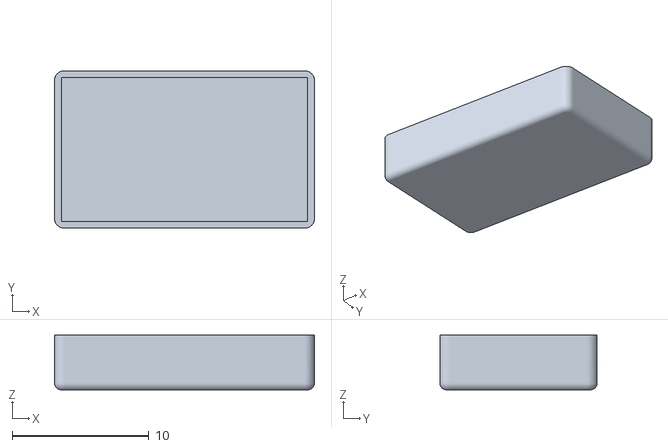
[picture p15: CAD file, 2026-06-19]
3D Models/ShellTest/4DS Shell test 180x105x40, +5S F=7 B=5.obj
19.0 x 11.5 x 4.00

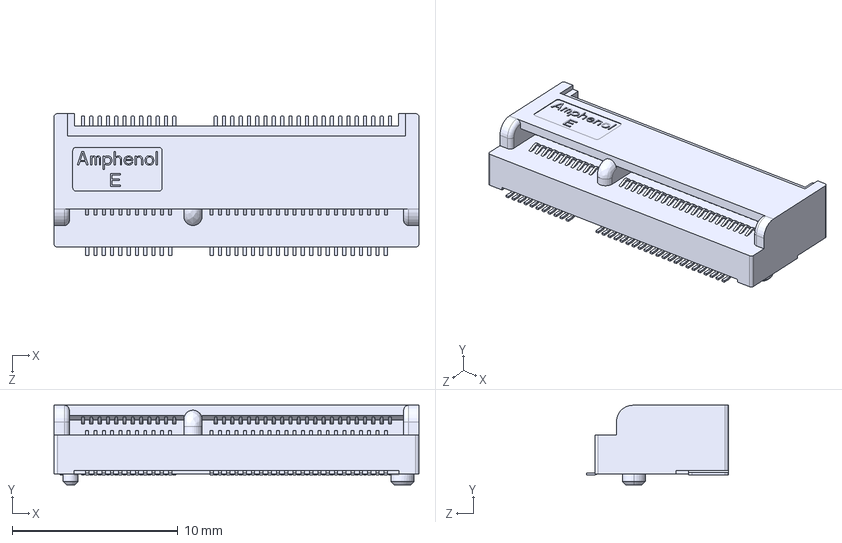
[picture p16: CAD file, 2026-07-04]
Motherboard/3D_models/MDT420E02001.step
22.0 x 4.80 x 8.55 mm

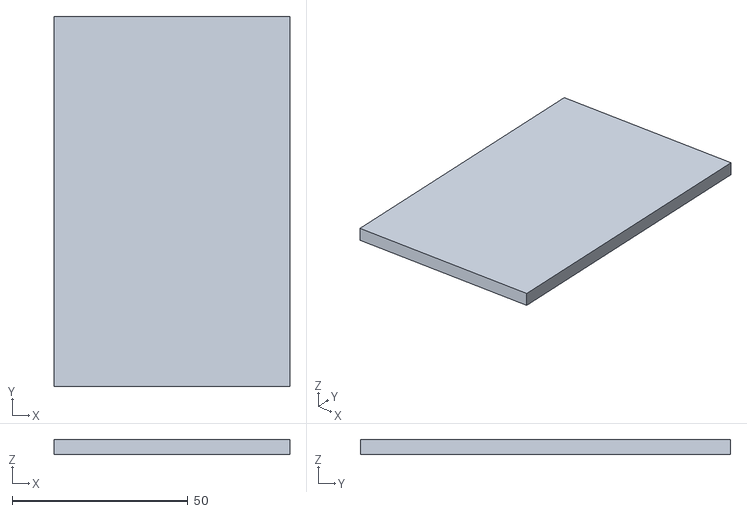
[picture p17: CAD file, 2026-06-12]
3D Models/General/BottomScreen.stl
67.2 x 105.4 x 4.36

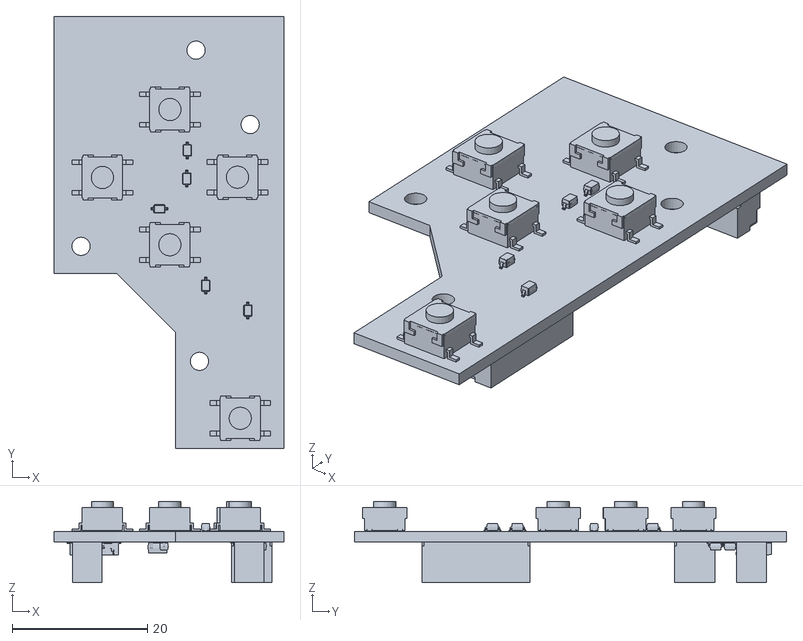
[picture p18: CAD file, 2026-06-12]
3D Models/ShellTest/CTRL_L_JUN11.stl
34.0 x 63.9 x 12.0

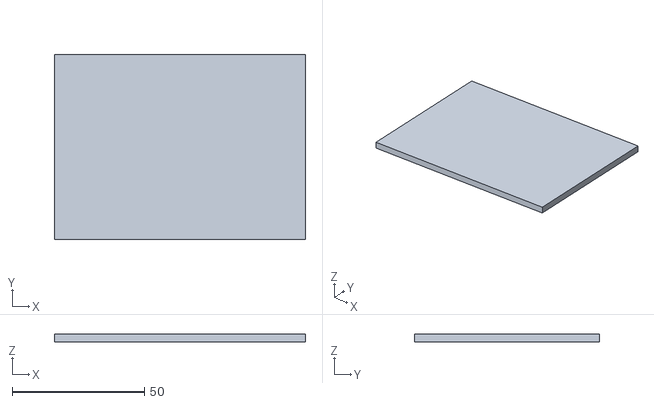
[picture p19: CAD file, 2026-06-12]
3D Models/General/Battery307095.stl
95.0 x 70.0 x 3.00

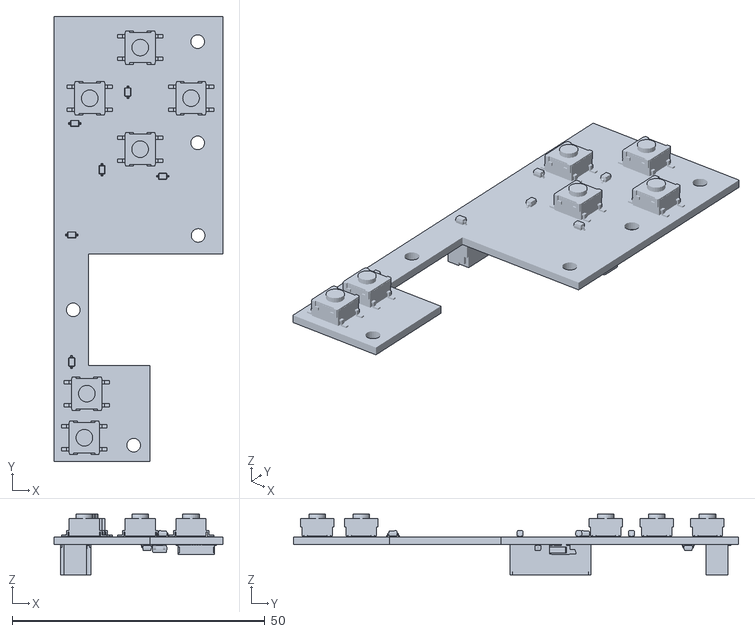
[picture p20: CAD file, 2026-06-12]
3D Models/ShellTest/CTRL_R_JUN11.stl
33.4 x 88.0 x 12.0

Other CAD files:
Motherboard/3D_models/MDT420M02001.step
3D Models/General/LattePandaCoolerFan.stl
3D Models/ShellTest/CTRL_L_SLIDERS_JUN11.stl
3D Models/ShellTest/4DS Shell test 175x95x30 +2.5S F=7 B=5 .obj
3D Models/General/3W_Speakers.stl
3D Models/Screws/fixh0020l00050_hex_screw_m2x5.stl
3D Models/Screws/fixh0025l00050_hex_screw_m25x5.stl
3D Models/Screws/fixh0030l00050_hex_screw_m3x5.stl
3D Models/Screws/fixh0040l00050_hex_screw_m4x5.stl
3D Models/Screws/fixh0050l00050_hex_screw_m5x5.3mf
3D Models/Screws/fixh0050l00050_hex_screw_m5x5.stl
3D Models/ShellTest/4DS Shell test 180x105x30, +2.5S F=7 B=5.obj
3D Models/ShellTest/4DS Shell test 180x95x30, +2.5S F=7 B=5.obj
Motherboard/3D_models/2086581001.step
Motherboard/3D_models/2086581001.stp
Motherboard/3D_models/48406-0001.stp

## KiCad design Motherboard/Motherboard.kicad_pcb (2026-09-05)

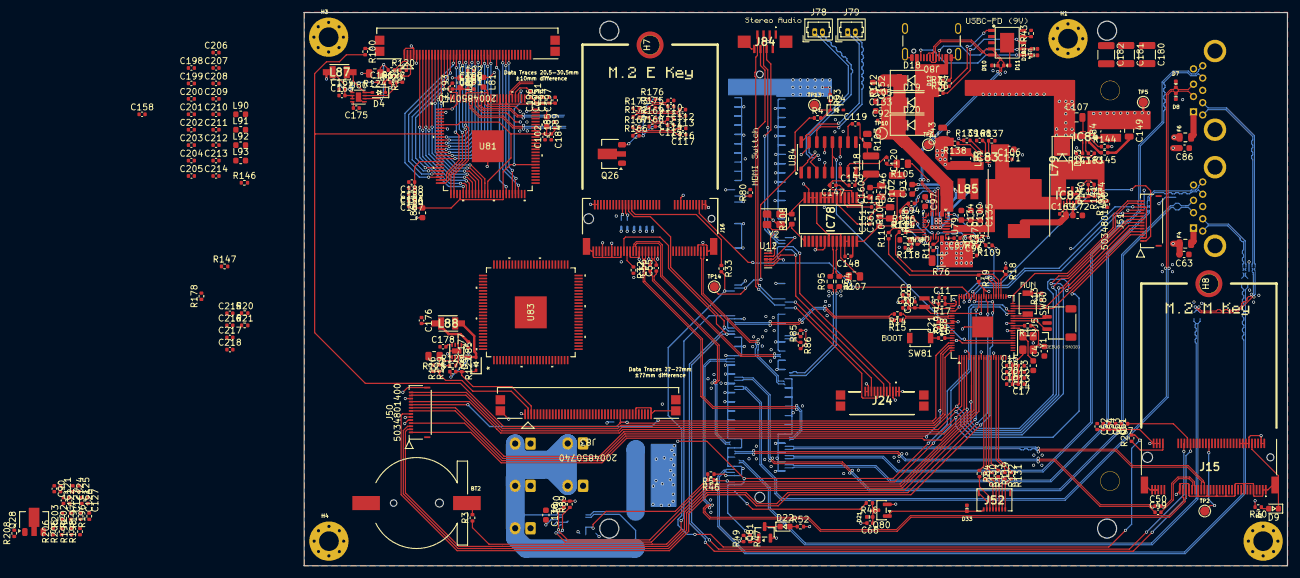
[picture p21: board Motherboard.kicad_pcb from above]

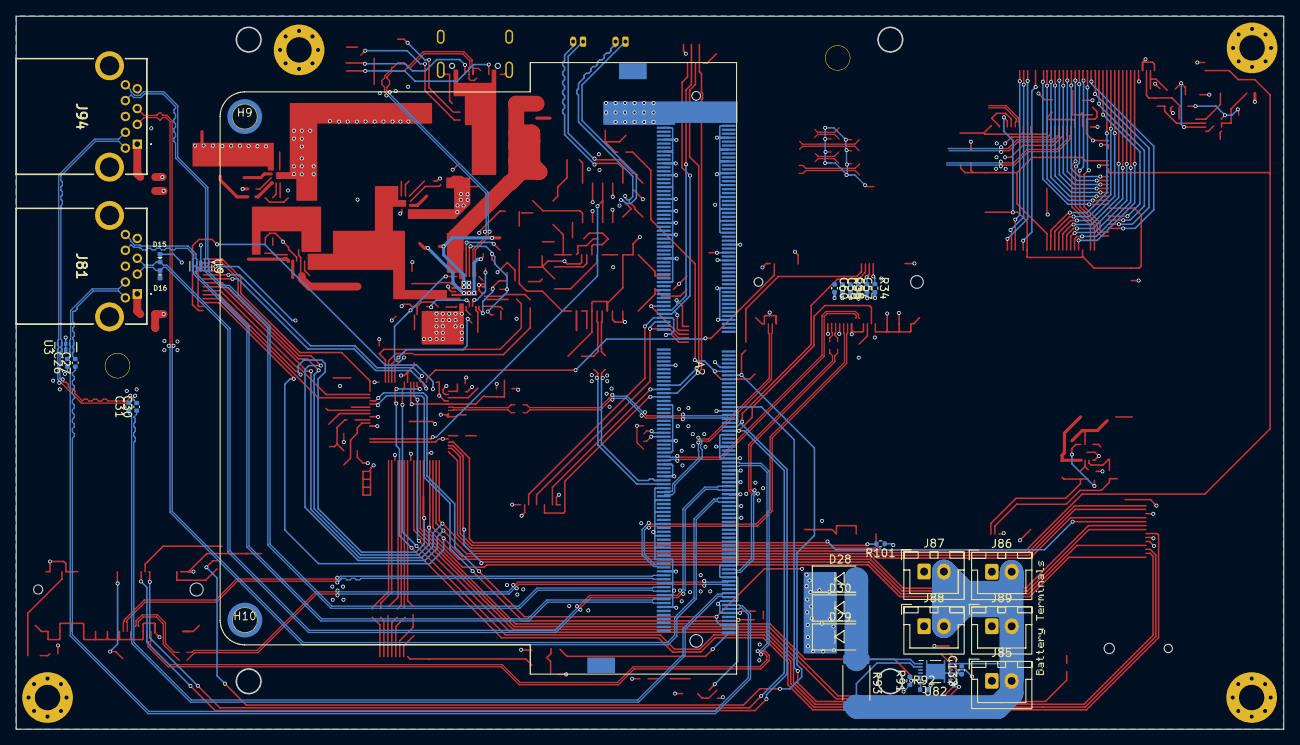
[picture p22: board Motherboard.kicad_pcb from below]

Board: 4 copper layers, 160.0 x 90.0 mm, 356 parts (34 on the bottom side), 319 nets.

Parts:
A2: LattePanda_Mu; LattePanda_Module_H8.0mm_Horizontal
BT2: Battery_Cell; Battery_Holder_CR1220_S8411-45R
C3, C4: 15pF; C_0603_1608Metric
C8, C9, C12, C13, C14, C15, C16, C17, C18, C20, C21, C26, C27, C30, C31, C52, C54, C58, C60: 100nF; C_0402_1005Metric
C10, C11, C19, C22, C94: 4.7uF; C_0402_1005Metric
C49, C50, C55, C56, C169: 220nF; C_0402_1005Metric
C51, C53, C57, C59, C90, C96, C102, C104, C106, C108, C110, C111, C112, C113, C114, C115, C116, C117, C121, C122, C123, C124, C125, C126, C127, C131, C150, C153, C158, C164, C170, C177, C198, C207, C208, C215, C216, C217, C218: 10uF; C_0402_1005Metric
C61, C66, C119, C120, C137, C147, C148, C151, C165, C166, C176, C179: 1uF; C_0402_1005Metric
C63, C86: 22uF; C_0603_1608Metric
C87: 1nF; C_0402_1005Metric
C92, C159, C184, C185, C186, C187, C188, C189, C190, C191, C192, C193, C194, C195, C196, C197, C199, C200, C201, C202, C203, C204, C205, C206, C209, C210, C211, C212, C213, C214: 0.1uF; C_0402_1005Metric
C93, C97: 47nF; C_0603_1608Metric
C100, C105, C133, C134, C135: 10uF; C_0603_1608Metric
C107: 10uF; C_0805_2012Metric
C118, C146: 100uF; C_1210_3225Metric
C138: 0.47uF; C_0603_1608Metric
C143, C149: 22uF; C_0805_2012Metric
C152, C172: 2.2uF; C_0603_1608Metric
C160, C161: 0.022uF; C_0603_1608Metric
C168, C183: 1.2nF; C_0402_1005Metric
C171: 100nF; C_0603_1608Metric
C173: 39nF; C_0402_1005Metric
C174: 91pF; C_0402_1005Metric
C175, C178: 10nF; C_0402_1005Metric
C180, C181, C182: 47uF; C_1210_3225Metric
D4, D5: 1N5819WS; D_SOD-323
D7, D8, D10, D11, D15, D16, D21, D33: ESD5V0B03; D_0402_1005Metric
D9, D22: LED_G; LED_0603_1608Metric
D12, D13, D14: PESD24VS1UL-N; D_0402_1005Metric
D18, D19, D20, D23, D28, D29, D30: SS54; D_SMA
D24: 3V3 Izt=5mA; D_SOD-323
F4, F6: 6V/2A; Fuse_0805_2012Metric
H1, H2, H3, H4: MountingHole_Pad; MountingHole_3.2mm_M3_Pad_Via
H7, H8: MountingHole_M2.0; MountingHole_3mm_M2_Pad_TopOnly
H9, H10: MountingHole_Pad; MountingHole_3mm_M2_Pad_TopOnly
IC78: PCM2704CDBR; SOP65P780X200-28N
IC82: TPS61288LRQQR; PTPS61288RQQR
IC83, IC84: TPS62903RPJR
J5: SM03B-SRSS-TB; JST_SH_SM03B-SRSS-TB_1x03-1MP_P1.00mm_Horizontal
J15: M.2 Socket M; MDT420M03001
J16: M.2 Socket E; PCIe_M.2_Connectors_P=0.5mm_H=4.2mm_KeyE
J24: 200485-0710; 2004850710
J50, J51: 5034801400
J52: 503480-0800; 5034800800
J78: Speaker_L; Molex_PicoBlade_53047-0210_1x02_P1.25mm_Vertical
J79: Speaker_R; Molex_PicoBlade_53047-0210_1x02_P1.25mm_Vertical
J80: USB_C_Receptacle_USB2.0_16P; USB_C_Receptacle_GCT_USB4105-xx-A_16P_TopMnt_Horizontal
J81, J94: GSB311A41EU
J83, J90: 2004850740; CON_2004850740
J84: FFC2A33-08-T-R; FFC2A3308TR
J85: JST_XHP2_Battery1; JST_XH_B2B-XH-A_1x02_P2.50mm_Vertical
J86: JST_XHP2_Battery2; JST_XH_B2B-XH-A_1x02_P2.50mm_Vertical
J87: JST_XHP2_Battery3; JST_XH_B2B-XH-A_1x02_P2.50mm_Vertical
J88: JST_XHP2_Battery4; JST_XH_B2B-XH-A_1x02_P2.50mm_Vertical
J89: JST_XHP2_Battery5; JST_XH_B2B-XH-A_1x02_P2.50mm_Vertical
L5: 3.3uH; L_pol_2016
L79: 7443330220; WE-HCC_109021
L81, L82, L86, L89, L90, L91, L92, L93: BLM18RK601SN1D; L_0603_1608Metric
L83, L84: 74438336010HT
L85: 74438336022HT
L87, L88: LQH32CN220K23L; LQH32DN100K23L
Q26, Q28: 2SK3018-TP; SOT-89-3
Q80, Q81: 2N7002; SOT-23
R3, R12, R13, R16, R37, R47: 1k/1%; R_0402_1005Metric
R4, R18, R19, R20, R21, R34, R35, R36, R49, R85, R86, R91, R92, R100, R101, R109, R110, R111, R115: 10k/1%; R_0402_1005Metric
R14, R15: 27R; R_0402_1005Metric
R17: 33R/1%; R_0402_1005Metric
R27, R29, R32, R33: 0R/1%; R_0402_1005Metric
R30, R52, R53: 2.2k/1%; R_0402_1005Metric
R43: 6.8k/1%; R_0402_1005Metric
R46, R48: 100R/1%; R_0402_1005Metric
R51, R80, R116, R138, R144: 100k/1%; R_0402_1005Metric
R76: 100R/1%; R_1206_3216Metric
R77: 4.7k/1%; R_0402_1005Metric
R84, R119: 150R/1%; R_0402_1005Metric
R89, R90: 5.1k/1%; R_0402_1005Metric
R93: 0.010R/1%; R_2512_6332Metric
R94, R95: 22R/1%; R_0603_1608Metric
R102, R106: 16R/1%; R_0805_2012Metric
R103, R105: 330R/1%; R_0805_2012Metric
R107: 1.5k/1%; R_0805_2012Metric
R108: 1M/1%; R_0603_1608Metric
R112: 2R/1%; R_0805_2012Metric
R113, R114: 127k/1%; R_0402_1005Metric
R117: 5.24k/1%; R_0402_1005Metric
R118: 30k/1%; R_0402_1005Metric
R120: 5.1R/1%; R_0402_1005Metric
R121, R122, R127, R128: 910k/1%; R_0402_1005Metric
R123, R126: 5k/1%; R_0402_1005Metric
R124, R125: 90.9k/1%; R_0805_2012Metric
R129: 10R/1%; R_0402_1005Metric
R130, R131, R132, R133: 47R/1%; R_0402_1005Metric
R137, R140, R143: 40.2k/1%; R_0402_1005Metric
R139: 249k/1%; R_0402_1005Metric
R141: 681k/1%; R_0402_1005Metric
R142: 48.7k/1%; R_0402_1005Metric
R145: 76.8k/1%; R_0402_1005Metric
R146, R147: 470R/1%; R_0402_1005Metric
R166, R167, R168, R169, R172, R173, R175, R176, R196, R197, R198, R199, R202, R203, R205, R206: 56k/1%; R_0402_1005Metric
R178, R208: 21.5k/1%; R_0402_1005Metric
SW80, SW81: SW_Push; SW_SPST_B3U-1000P
TH78: 10k/1%; R_0603_1608Metric
TP2, TP5, TP6, TP10, TP13, TP14: TestPoint; TestPoint_Pad_D1.5mm
U3, U9, U12: D3V3XA4B10LP-7; Diodes_UDFN-10_1x2.5mm_P0.5mm
U14: CH224K; ESSOP-10-1EP_3.9x5mm_P1.0mm_EP3.2x2.3
U79: BQ25798; Texas_RQM0029A_VQFN-29_4x4mm_P0.4mm
U80, U85: PAM2841G; DFN-8-1EP_2x2mm_P0.5mm_EP0.86x1.55mm
U81, U83: TFP401PZP; PZP100_5P2X5P2
U82: BQ27441DRZT-G1A; Texas_S-PDSO-N12
U84: PAM8403D; SOIC-16_3.9x9.9mm_P1.27mm
U88: RP2354B; QFN-80-1EP_10x10mm_P0.4mm_EP3.4x3.4mm
Y1, Y2: ABM8-272-T3; Crystal_SMD_3225-4Pin_3.2x2.5mm
kibuzzard-6A7CAF20: G***; kibuzzard-6A7CAF20
kibuzzard-6A7CAF29: G***; kibuzzard-6A7CAF29
kibuzzard-6A7CAF45: G***; kibuzzard-6A7CAF45
kibuzzard-6A7DF5CF: G***; kibuzzard-6A7DF5CF
kibuzzard-6A7DF57A: G***; kibuzzard-6A7DF57A
kibuzzard-6A74CEFD: G***; kibuzzard-6A74CEFD
kibuzzard-6A74CF1D: G***; kibuzzard-6A74CF1D
kibuzzard-6A74CF57: G***; kibuzzard-6A74CF57
kibuzzard-6A760A01: G***; kibuzzard-6A760A01

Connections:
+1V1: C8.2, C9.2, C10.2, C22.1, L5.2, U88.10 (DVDD), U88.32 (DVDD), U88.51 (DVDD), U88.65 (VREG_FB)
+3V3: C12.2, C13.2, C14.2, C15.2, C16.2, C17.2, C18.2, C19.2, C20.2, C21.2, C51.2, C52.2, C53.2, C54.2, C57.2, C58.2, C59.2, C60.2, C143.1, C164.2, C165.2, C176.2, C177.2, IC78.7 (VDD), IC78.10 (VBUS), IC78.25 (TEST1), IC78.26 (TEST0), IC78.27 (~SSPND), IC83.3 (VOS), J15.2 (3.3V), J15.4 (3.3V), J15.12 (3.3V), J15.14 (3.3V), J15.16 (3.3V), J15.18 (3.3V), J15.70 (3.3V), J15.72 (3.3V), J15.74 (3.3V), J16.2 (3.3V), J16.4 (3.3V), J16.72 (3.3V), J16.74 (3.3V), J24.2, J50.6, J50.12, J51.2, J51.12, J83.4, J84.3, J90.4, L81.1, L82.1, L83.2, L86.1, L87.1, L87.3, L88.1, L88.3, L89.1, L90.1, L91.1, L92.1, L93.1, R17.2, R18.1, R19.2, R20.1, R21.2, R30.2, R34.2, R35.1, R52.2, R89.2, R90.2, R92.2, R100.1, R101.1, R107.1, R109.1, R138.2, R146.1, R147.1, TP6.1 (1_1), U80.2 (VIN), U80.3 (ENA), U81.2 (*PD), U81.3 (ST), U81.7 (*STAG), U81.99 (RSVD), U81.100 (OCK_INV), U83.2 (*PD), U83.3 (ST), U83.7 (*STAG), U83.99 (RSVD), U83.100 (OCK_INV), U84.4 (PVDD), U84.6 (VDD), U84.13 (PVDD), U85.2 (VIN), U85.3 (ENA), U88.5 (IOVDD), U88.15 (IOVDD), U88.24 (IOVDD), U88.29 (IOVDD), U88.41 (IOVDD), U88.50 (IOVDD), U88.59 (ADC_AVDD), U88.60 (IOVDD), U88.64 (VREG_VIN), U88.68 (USB_OTP_VDD), U88.69 (QSPI_IOVDD), U88.76 (IOVDD)
+5V: C63.2, C86.2, C149.1, F4.1, F6.1, IC84.3 (VOS), L84.2, R144.2, TP5.1 (1_1)
+9V: D12.1 (K), D18.2 (A), D19.2 (A), D20.2 (A), J80.A4 (VBUS), J80.A9 (VBUS), J80.B4 (VBUS), J80.B9 (VBUS), R36.1, R37.1
+BATT: A2.115 (VBAT), R3.1
/EXIO/Col1: J50.10, U88.77 (GPIO0)
/EXIO/Col2: J50.4, U88.78 (GPIO1)
/EXIO/Col3: J51.4, U88.38 (GPIO30)
/EXIO/Col4: J51.6, U88.39 (GPIO31)
/EXIO/LED_PWR_B: R131.1, U88.17 (GPIO17)
/EXIO/LED_PWR_G: R132.1, U88.16 (GPIO16)
/EXIO/LED_PWR_R: R119.1, U88.14 (GPIO15)
/EXIO/LED_WiFi_B: R133.1, U88.13 (GPIO14)
/EXIO/LED_WiFi_G: R130.1, U88.12 (GPIO13)
/EXIO/LED_WiFi_R: R84.1, U88.11 (GPIO12)
/EXIO/L_ADC_X: J50.2, U88.52 (GPIO41/ADC1)
/EXIO/L_ADC_Y: J50.3, U88.49 (GPIO40/ADC0)
/EXIO/PWR_Button: D33.1 (A1), J52.8, Q80.1 (G)
/EXIO/RPi_HALL_L: J50.14, U88.80 (GPIO3)
/EXIO/RPi_HALL_R: J51.14, U88.40 (GPIO32)
/EXIO/R_ADC_X: J51.10, U88.54 (GPIO43/ADC3)
/EXIO/R_ADC_Y: J51.9, U88.55 (GPIO44/ADC4)
/EXIO/Row1: J50.11, J51.13, U88.2 (GPIO5)
/EXIO/Row2: J50.8, J51.8, U88.4 (GPIO7)
/EXIO/Row3: J50.13, J51.7, U88.1 (GPIO4)
/EXIO/Row4: J50.9, J51.3, U88.3 (GPIO6)
/EXIO/Row5: J50.1, J51.5, U88.6 (GPIO8)
/EXIO/SL_BRI: J51.1, U88.58 (GPIO47/ADC7)
/EXIO/SL_VOL: J50.7, U88.53 (GPIO42/ADC2)
/LattePanda Module/AMP_L: C120.1, U84.7 (INL)
/LattePanda Module/AMP_R: C119.1, U84.10 (INR)
/LattePanda Module/Audio_D+: A2.76 (USB2_P7+), R94.2
/LattePanda Module/Audio_D-: A2.78 (USB2_P7-), R95.1
/LattePanda Module/Audio_DX+: IC78.9 (D+), R94.1, R107.2
/LattePanda Module/Audio_DX-: IC78.8 (D-), R95.2
/LattePanda Module/DDIB_INT: A2.124 (GPP_F13), J24.9
/LattePanda Module/DDIB_RST: A2.120 (GPP_F15), J24.7
/LattePanda Module/DDIB_TOUCH_SCL: A2.152 (I2C3_SDA), J24.3, U12.5, U12.6 (NC)
/LattePanda Module/DDIB_TOUCH_SDA: A2.150 (I2C3_SCL), J24.5, U12.4, U12.7 (NC)
/LattePanda Module/DDIB_TX0+: A2.217 (DDIB_TX0+), C90.1
/LattePanda Module/DDIB_TX0-: A2.215 (DDIB_TX0-), C121.1
/LattePanda Module/DDIB_TX1+: A2.211 (DDIB_TX1+), C122.1
/LattePanda Module/DDIB_TX1-: A2.209 (DDIB_TX1-), C123.1
/LattePanda Module/DDIB_TX2+: A2.205 (DDIB_TX2+), C124.1
/LattePanda Module/DDIB_TX2-: A2.203 (DDIB_TX2-), C125.1
/LattePanda Module/DDIB_TX3+: A2.199 (DDIB_TX3+), C126.1
/LattePanda Module/DDIB_TX3-: A2.197 (DDIB_TX3-), C127.1
/LattePanda Module/HSIO_0_TX+: A2.13 (HSIO0_TX+), C27.1
/LattePanda Module/HSIO_0_TX-: A2.15 (HSIO0_TX-), C26.1
/LattePanda Module/HSIO_1_TX+: A2.19 (HSIO1_TX+), C31.1
/LattePanda Module/HSIO_1_TX-: A2.21 (HSIO1_TX-), C30.1
/LattePanda Module/HSIO_2_RX+: A2.28 (HSIO2_RX+), J15.43 (PERp0/SATA-B-)
/LattePanda Module/HSIO_2_RX-: A2.30 (HSIO2_RX-), J15.41 (PERn0/SATA-B+)
/LattePanda Module/HSIO_2_TX+: A2.25 (HSIO2_TX+), C49.1
/LattePanda Module/HSIO_2_TX-: A2.27 (HSIO2_TX-), C50.1
/LattePanda Module/HSIO_3_RX+: A2.34 (HSIO3_RX+), J16.41 (PERp0)
/LattePanda Module/HSIO_3_RX-: A2.36 (HSIO3_RX-), J16.43 (PERn0)
/LattePanda Module/HSIO_3_TX+: A2.31 (HSIO3_TX+), C55.1
/LattePanda Module/HSIO_3_TX-: A2.33 (HSIO3_TX-), C56.1
/LattePanda Module/LOUT+: J78.1, U84.3 (LOUT-)
/LattePanda Module/LOUT-: J78.2, U84.1 (LOUT+)
/LattePanda Module/REFCLK0+: A2.85 (REFCLK0+), J15.53 (REFCLKn)
/LattePanda Module/REFCLK0-: A2.87 (REFCLK0-), J15.55 (REFCLKp)
/LattePanda Module/REFCLK3+: A2.88 (REFCLK3+), J16.47 (REFCLKp0)
/LattePanda Module/REFCLK3-: A2.90 (REFCLK3-), J16.49 (REFCLKn0)
/LattePanda Module/ROUT+: J79.1, U84.16 (ROUT+)
/LattePanda Module/ROUT-: J79.2, U84.14 (ROUT-)
/LattePanda Module/RP+: R14.1, U88.66 (USB_DM)
/LattePanda Module/RP-: R15.1, U88.67 (USB_DP)
/LattePanda Module/RPI_BAT_GPO: R92.1, U82.12 (GPOUT), U88.7 (GPIO9)
/LattePanda Module/RPI_BAT_SCL: R21.1, R89.1, U82.1 (SDA), U88.9 (GPIO11)
/LattePanda Module/RPI_BAT_SDA: R20.2, R90.1, U82.2 (SCL), U88.8 (GPIO10)
/LattePanda Module/RPI_BAT_STAT: R109.2, U79.1 (STAT), U88.46 (GPIO37)
/LattePanda Module/RPR+: A2.111 (USB2_P5+), R14.2
/LattePanda Module/RPR-: A2.109 (USB2_P5-), R15.2
/LattePanda Module/RPi_5A_INT: R115.1, U88.45 (GPIO36)
/LattePanda Module/RPi_5A_SCL: R19.1, R110.1, U88.44 (GPIO35)
/LattePanda Module/RPi_5A_SDA: R18.2, R111.1, U88.43 (GPIO34)
/LattePanda Module/RPi_LCD_EN: J83.31, J90.31, R100.2, R101.2, U81.8 (SCDT), U81.9 (*PDO), U83.8 (SCDT), U83.9 (*PDO), U88.79 (GPIO2)
/LattePanda Module/RPi_PAM_LPWR: U84.5 (~MUTE), U84.12 (~SHDN), U88.25 (GPIO24)
/LattePanda Module/SLS_S3: A2.7 (SLS_S3), R46.1, U88.36 (GPIO28)
/LattePanda Module/SUSCLK_WIFI: A2.131 (SUSCLK), R29.2, R33.2
/LattePanda Module/SWCLK: J5.1, U88.33 (SWCLK)
/LattePanda Module/SWD: J5.3, U88.34 (SWDIO)
/LattePanda Module/TCP0_INT: A2.126 (GPP_F12), J84.6
/LattePanda Module/TCP0_RST: A2.122 (GPP_F14), J84.7
/LattePanda Module/TCP0_TOUCH_SCL: A2.154 (I2C2_SCL), J84.4, U12.2, U12.9 (NC)
/LattePanda Module/TCP0_TOUCH_SDA: A2.156 (I2C2_SDA), J84.5, U12.1, U12.10 (NC)
/LattePanda Module/TCP0_TX0+: A2.247 (TCP0_TX0+), C110.1
/LattePanda Module/TCP0_TX0-: A2.245 (TCP0_TX0-), C111.1
/LattePanda Module/TCP0_TX1+: A2.241 (TCP0_TXRX0+), C112.1
/LattePanda Module/TCP0_TX1-: A2.239 (TCP0_TXRX0-), C113.1
/LattePanda Module/TCP0_TX2+: A2.235 (TCP0_TX1+), C114.1
/LattePanda Module/TCP0_TX2-: A2.233 (TCP0_TX1-), C115.1
/LattePanda Module/TCP0_TX3+: A2.229 (TCP0_TXRX1+), C116.1
/LattePanda Module/TCP0_TX3-: A2.227 (TCP0_TXRX1-), C117.1
/LattePanda Module/USB_2_P7+: A2.70 (USB2_P4+), J16.3 (USB_D+)
/LattePanda Module/USB_2_P7-: A2.72 (USB2_P4-), J16.5 (USB_D-)
/LattePanda Module/WiFi_M2E_LED: J16.6 (~LED_1), U88.56 (GPIO45/ADC5)
/LattePanda Module/~PWR_SW: A2.1 (~PWRBTN), R48.2
/LattePanda Module/~USB_BOOT: R16.1, SW81.1
/M.2 E&M Key/CON_PCIE_TX_0+: C55.2, J16.35 (PETp0)
/M.2 E&M Key/CON_PCIE_TX_0-: C56.2, J16.37 (PETn0)
/M.2 E&M Key/CON_PCIE_TX_1+: C49.2, J15.49 (PETp0/SATA-A+)
/M.2 E&M Key/CON_PCIE_TX_1-: C50.2, J15.47 (PETn0/SATA-A-)
/M.2 E&M Key/~CLKREQE: J16.53 (~CLKREQ0), R32.1
/M.2 E&M Key/~CLKREQM: J15.52 (~CLKREQ), R27.1
/PSU/9VIn: D23.2 (A), IC82.5 (VOUT), IC82.13 (VOUT), R141.2
/PSU/BAT+: C96.1, C153.1, D28.1 (K), D29.1 (K), D30.1 (K), R76.1, U79.22 (BAT), U79.23 (BAT)
/PSU/B_RAW: C137.2, J85.2, J86.2, J87.2, J88.2, J89.2, R93.2, U82.6 (BAT), U82.8 (SRP)
/PSU/CC1: D13.1 (K), J80.A5 (CC1), U14.7 (CC1)
/PSU/CC2: D14.1 (K), J80.B5 (CC2), U14.6 (CC2)
/PSU/PWR_C_D+: D11.2 (A2), J80.A6 (D+), J80.B6 (D+), U14.4 (DP), U79.6 (D+)
/PSU/PWR_C_D-: D10.2 (A2), J80.A7 (D-), J80.B7 (D-), U14.5 (DM), U79.7 (D-)
/PSU/SYS: C106.1, C170.1, C171.2, C215.1, C216.1, C217.1, C218.1, IC82.6 (EN), IC82.7 (VIN), IC82.14 (VIN), IC83.5 (EN), IC83.6 (VIN), L79.1, U79.25 (SYS)
/RGB/B0: J83.5, U83.30 (QE16)
/RGB/B1: J83.6, U83.31 (QE17)
/RGB/B2: J83.7, U83.32 (QE18)
/RGB/B3: J83.8, U83.33 (QE19)
/RGB/B4: J83.9, U83.34 (QE20)
/RGB/B5: J83.10, U83.35 (QE21)
/RGB/B6: J83.11, U83.36 (QE22)
/RGB/B7: J83.12, U83.37 (QE23)
/RGB/B8: J83.13, U83.20 (QE8)
/RGB/B9: J83.14, U83.21 (QE9)
/RGB/B10: J83.15, U83.22 (QE10)
/RGB/B11: J83.16, U83.23 (QE11)
/RGB/B12: J83.17, U83.24 (QE12)
/RGB/B13: J83.18, U83.25 (QE13)
/RGB/B14: J83.19, U83.26 (QE14)
/RGB/B15: J83.20, U83.27 (QE15)
/RGB/B16: J83.21, U83.10 (QE0)
/RGB/B17: J83.22, U83.11 (QE1)
/RGB/B18: J83.23, U83.12 (QE2)
/RGB/B19: J83.24, U83.13 (QE3)
/RGB/B20: J83.25, U83.14 (QE4)
/RGB/B21: J83.26, U83.15 (QE5)
/RGB/B22: J83.27, U83.16 (QE6)
/RGB/B23: J83.28, U83.17 (QE7)
/RGB/B-AVDD: C207.2, C209.1, C211.1, C213.1, C214.1, L92.2, U83.82 (AVDD), U83.84 (AVDD), U83.88 (AVDD), U83.95 (AVDD)
/RGB/B-DE: J83.30, U83.46 (DE)
/RGB/B-DVDD: C208.2, C210.1, C212.1, L93.2, U83.6 (DVDD), U83.38 (DVDD), U83.67 (DVDD)
/RGB/B-HS: J83.32, U83.48 (HSYNC)
/RGB/B-OVDD: C198.2, C200.1, C202.1, C204.1, C206.1, L91.2, U83.18 (OVDD), U83.29 (OVDD), U83.43 (OVDD), U83.57 (OVDD), U83.78 (OVDD)
/RGB/B-PCK: J83.34, U83.44 (ODCK)
/RGB/B-PVDD: C158.2, C199.1, C201.1, C203.1, C205.1, L90.2, U83.97 (PVDD)
/RGB/B-VS: J83.33, U83.47 (VSYNC)
/RGB/DDIB_CK+: C126.2, R197.1, U83.93 (RXC+)
/RGB/DDIB_CK-: C127.2, R196.1, U83.94 (RXC-)
/RGB/DDIB_D0+: C124.2, R199.1, U83.90 (RX0+)
/RGB/DDIB_D0-: C125.2, R198.1, U83.91 (RX0-)
/RGB/DDIB_D1+: C122.2, R203.1, U83.85 (RX1+)
/RGB/DDIB_D1-: C123.2, R202.1, U83.86 (RX1-)
/RGB/DDIB_D2+: C90.2, R206.1, U83.80 (RX2+)
/RGB/DDIB_D2-: C121.2, R205.1, U83.81 (RX2-)
/RGB/P0: J90.5, U81.30 (QE16)
/RGB/P1: J90.6, U81.31 (QE17)
/RGB/P2: J90.7, U81.32 (QE18)
/RGB/P3: J90.8, U81.33 (QE19)
/RGB/P4: J90.9, U81.34 (QE20)
/RGB/P5: J90.10, U81.35 (QE21)
/RGB/P6: J90.11, U81.36 (QE22)
/RGB/P7: J90.12, U81.37 (QE23)
/RGB/P8: J90.13, U81.20 (QE8)
/RGB/P9: J90.14, U81.21 (QE9)
/RGB/P10: J90.15, U81.22 (QE10)
/RGB/P11: J90.16, U81.23 (QE11)
/RGB/P12: J90.17, U81.24 (QE12)
/RGB/P13: J90.18, U81.25 (QE13)
/RGB/P14: J90.19, U81.26 (QE14)
/RGB/P15: J90.20, U81.27 (QE15)
/RGB/P16: J90.21, U81.10 (QE0)
/RGB/P17: J90.22, U81.11 (QE1)
/RGB/P18: J90.23, U81.12 (QE2)
/RGB/P19: J90.24, U81.13 (QE3)
/RGB/P20: J90.25, U81.14 (QE4)
/RGB/P21: J90.26, U81.15 (QE5)
/RGB/P22: J90.27, U81.16 (QE6)
/RGB/P23: J90.28, U81.17 (QE7)
/RGB/P-AVDD: C131.2, C194.1, C195.1, C196.1, C197.1, L81.2, U81.82 (AVDD), U81.84 (AVDD), U81.88 (AVDD), U81.95 (AVDD)
/RGB/P-DE: J90.34, U81.46 (DE)
/RGB/P-DVDD: C102.2, C184.1, C185.1, L89.2, U81.6 (DVDD), U81.38 (DVDD), U81.67 (DVDD)
/RGB/P-HS: J90.32, U81.48 (HSYNC)
/RGB/P-OVDD: C104.2, C186.1, C187.1, C188.1, C189.1, L86.2, U81.18 (OVDD), U81.29 (OVDD), U81.43 (OVDD), U81.57 (OVDD), U81.78 (OVDD)
/RGB/P-PCK: J90.30, U81.44 (ODCK)
/RGB/P-PVDD: C108.2, C190.1, C191.1, C192.1, C193.1, L82.2, U81.97 (PVDD)
/RGB/P-VS: J90.33, U81.47 (VSYNC)
/RGB/TMDS_CK+: C116.2, R167.1, U81.93 (RXC+)
/RGB/TMDS_CK-: C117.2, R166.1, U81.94 (RXC-)
/RGB/TMDS_D0+: C114.2, R169.1, U81.90 (RX0+)
/RGB/TMDS_D0-: C115.2, R168.1, U81.91 (RX0-)
/RGB/TMDS_D1+: C112.2, R173.1, U81.85 (RX1+)
/RGB/TMDS_D1-: C113.2, R172.1, U81.86 (RX1-)
/RGB/TMDS_D2+: C110.2, R176.1, U81.80 (RX2+)
/RGB/TMDS_D2-: C111.2, R175.1, U81.81 (RX2-)
/USB/CON_USB3_D_N: A2.73 (USB2_P2-), D16.2 (A2), J81.2 (D-)
/USB/CON_USB3_D_P: A2.75 (USB2_P2+), D15.2 (A2), J81.3 (D+)
/USB/CON_USB3_SSRX_N: A2.18 (HSIO0_RX-), J81.5 (STDA_SSRX-), U9.4, U9.7 (NC)
/USB/CON_USB3_SSRX_P: A2.16 (HSIO0_RX+), J81.6 (STDA_SSRX+), U9.5, U9.6 (NC)
/USB/CON_USB3_SSTX_N: C26.2, J81.8 (STDA_SSTX-), U3.4, U3.7 (NC)
/USB/CON_USB3_SSTX_P: C27.2, J81.9 (STDA_SSTX+), U3.5, U3.6 (NC)
/USB/CON_USB4_D_N: A2.67 (USB2_P1-), D8.2 (A2), J94.2 (D-)
/USB/CON_USB4_D_P: A2.69 (USB2_P1+), D7.2 (A2), J94.3 (D+)
/USB/CON_USB4_SSRX_N: A2.24 (HSIO1_RX-), J94.5 (STDA_SSRX-), U9.1, U9.10 (NC)
/USB/CON_USB4_SSRX_P: A2.22 (HSIO1_RX+), J94.6 (STDA_SSRX+), U9.2, U9.9 (NC)
/USB/CON_USB4_SSTX_N: C30.2, J94.8 (STDA_SSTX-), U3.1, U3.10 (NC)
/USB/CON_USB4_SSTX_P: C31.2, J94.9 (STDA_SSTX+), U3.2, U3.9 (NC)
/~PLT_RST: A2.105 (~PLTRST), J15.50 (~PERST), J16.52 (~PERST0)
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

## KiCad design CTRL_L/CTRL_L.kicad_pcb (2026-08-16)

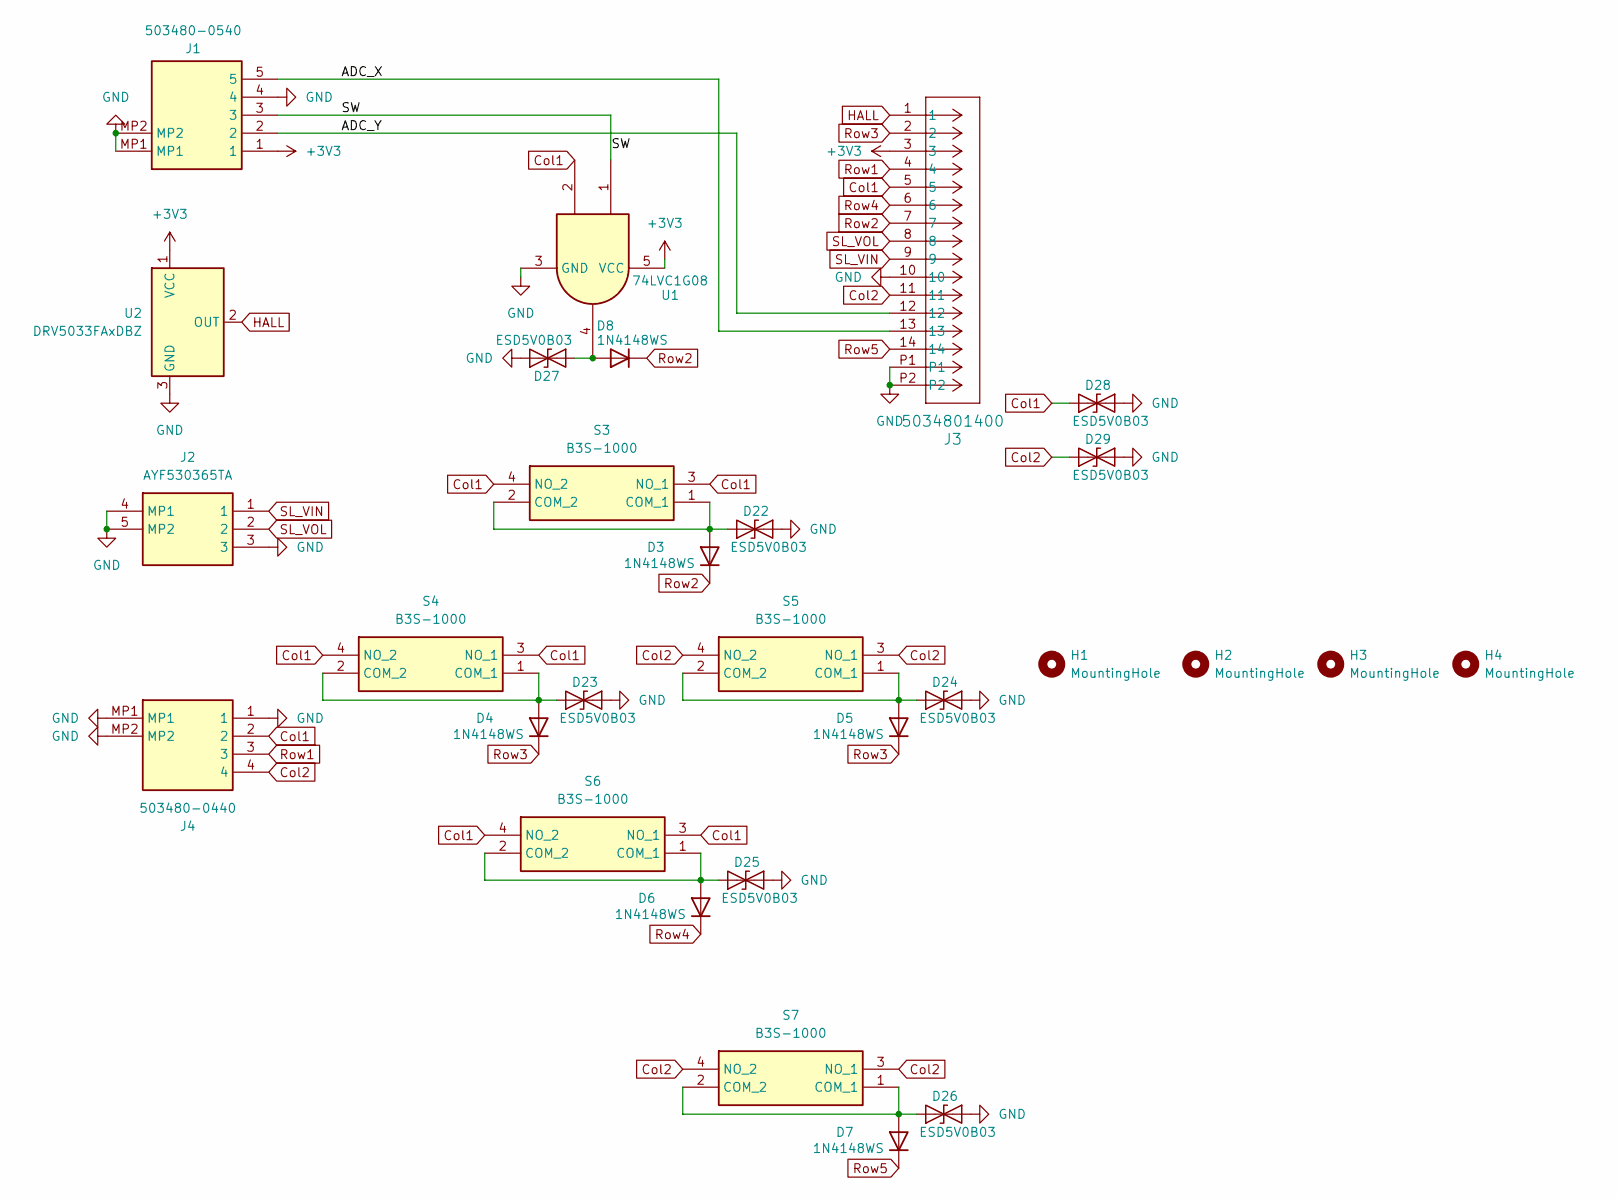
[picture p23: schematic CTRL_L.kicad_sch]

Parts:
D3, D4, D5, D6, D7, D8: 1N4148WS; D_SOD-323; MPN 1N4148WS; LCSC Part C917117
D22, D23, D24, D25, D26, D27, D28, D29: ESD5V0B03; D_0402_1005Metric; MPN ESD5V0B03-1006; LCSC Part C521894
H1, H2, H3, H4: MountingHole; MountingHole_2.7mm_M2.5; LCSC Part N/A
J1: 503480-0540; 5034800540; Mouser Part Number 538-503480-0540
J2: AYF530365TA; AYF530365T; Mouser Part Number 667-AYF530365TA
J3: 5034801400; MPN 5034801400; LCSC Part C505360
J4: 503480-0440; 5034800440; Mouser Part Number 538-503480-0440
S3, S4, S5, S6, S7: B3S-1000; B3S1000; Mouser Part Number 653-B3S-1000
U1: 74LVC1G08; SOT-23-5; MPN 74LVC1G08GV; LCSC Part C53185136
U2: DRV5033FAxDBZ; SOT-23; MPN DRV5033FAQDBZR; LCSC Part C2869057

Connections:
+3V3: J1.1, J3.3, U1.5 (VCC), U2.1 (VCC)
/ADC_X: J1.5, J3.13
/ADC_Y: J1.2, J3.12
/SW: J1.3, U1.1
Col1: D28.2 (A2), J3.5, J4.2, S3.3 (NO_1), S3.4 (NO_2), S4.3 (NO_1), S4.4 (NO_2), S6.3 (NO_1), S6.4 (NO_2), U1.2
Col2: D29.2 (A2), J3.11, J4.4, S5.3 (NO_1), S5.4 (NO_2), S7.3 (NO_1), S7.4 (NO_2)
GND: D22.1 (A1), D23.1 (A1), D24.1 (A1), D25.1 (A1), D26.1 (A1), D27.1 (A1), D28.1 (A1), D29.1 (A1), J1.4, J1.MP1, J1.MP2, J2.3, J2.4 (MP1), J2.5 (MP2), J3.10, J3.P1, J3.P2, J4.1, J4.MP1, J4.MP2, U1.3 (GND), U2.3 (GND)
HALL: J3.1, U2.2 (OUT)
unnamed: D3.2 (A), D22.2 (A2), S3.1 (COM_1), S3.2 (COM_2)
unnamed: D4.2 (A), D23.2 (A2), S4.1 (COM_1), S4.2 (COM_2)
unnamed: D5.2 (A), D24.2 (A2), S5.1 (COM_1), S5.2 (COM_2)
unnamed: D6.2 (A), D25.2 (A2), S6.1 (COM_1), S6.2 (COM_2)
unnamed: D7.2 (A), D26.2 (A2), S7.1 (COM_1), S7.2 (COM_2)
unnamed: D8.2 (A), D27.2 (A2), U1.4
Row1: J3.4, J4.3
Row2: D3.1 (K), D8.1 (K), J3.7
Row3: D4.1 (K), D5.1 (K), J3.2
Row4: D6.1 (K), J3.6
Row5: D7.1 (K), J3.14
SL_VIN: J2.1, J3.9
SL_VOL: J2.2, J3.8

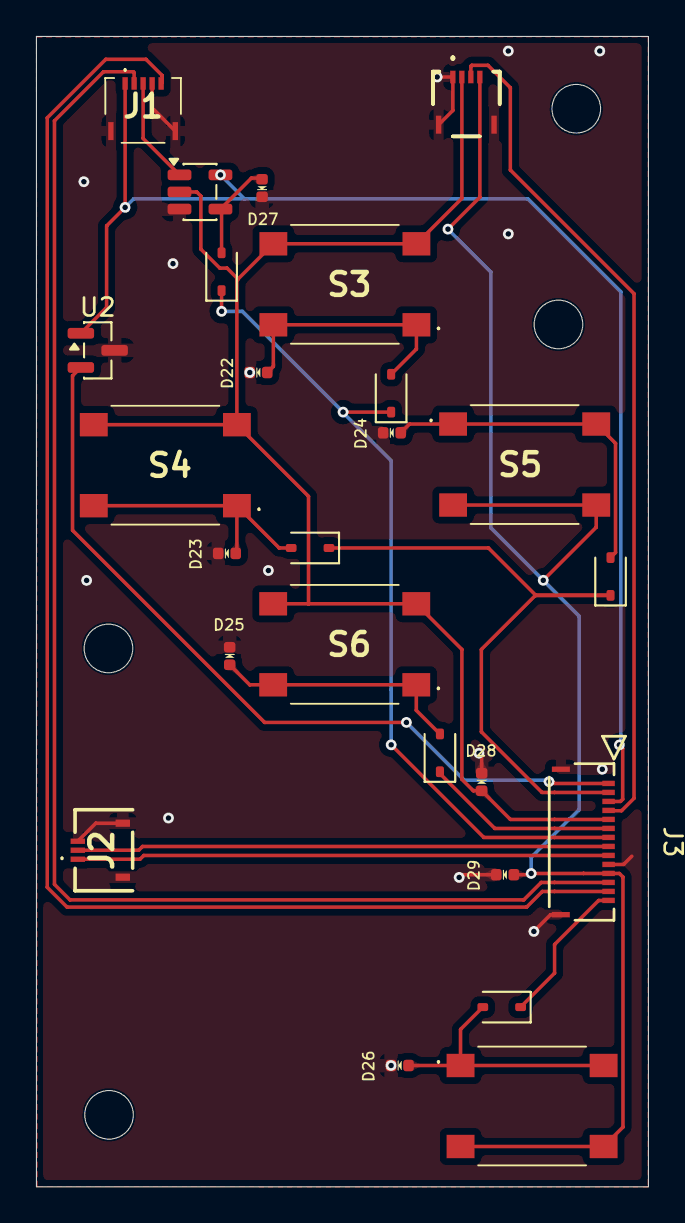
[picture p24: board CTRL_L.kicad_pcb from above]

Board: 2 copper layers, 34.0 x 63.9 mm, 31 parts (2 on the bottom side), 21 nets.

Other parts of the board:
kibuzzard-6A186FEC: G***; kibuzzard-6A186FEC
kibuzzard-6A187131: G***; kibuzzard-6A187131

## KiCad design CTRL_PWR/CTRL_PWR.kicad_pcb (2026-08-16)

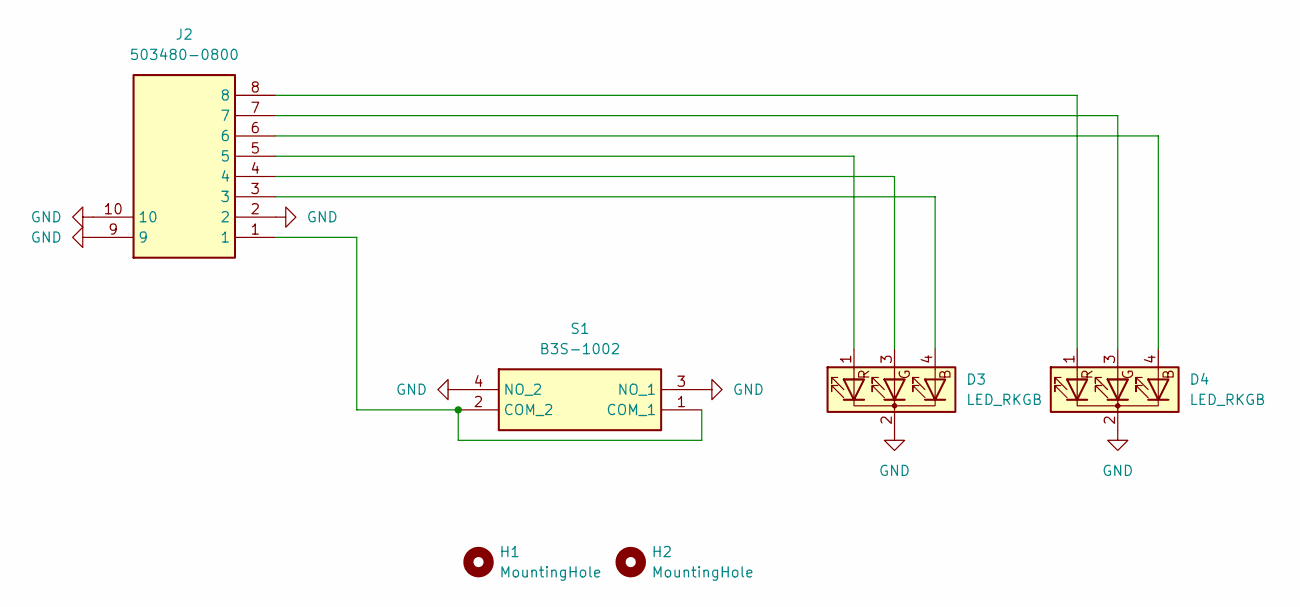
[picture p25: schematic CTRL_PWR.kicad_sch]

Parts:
D3, D4: LED_RKGB; LED_D5.0mm-4_RGB; MPN TJ-L5FCMXHTCSLCRGB-A5; LCSC Part C2837020
H1, H2: MountingHole; MountingHole_2.7mm_M2.5; LCSC Part N/A
J2: 503480-0800; 5034800800; Manufacturer_Part_Number 503480-0800
S1: B3S-1002; B3S1002; MPN B3S-1002; LCSC Part C2733654

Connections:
GND: D3.2 (K), D4.2 (K), J2.2, J2.9, J2.10, S1.3 (NO_1), S1.4 (NO_2)
unnamed: D3.4 (BA), J2.3
unnamed: D3.3 (GA), J2.4
unnamed: D3.1 (RA), J2.5
unnamed: D4.4 (BA), J2.6
unnamed: D4.3 (GA), J2.7
unnamed: D4.1 (RA), J2.8
unnamed: J2.1, S1.1 (COM_1), S1.2 (COM_2)

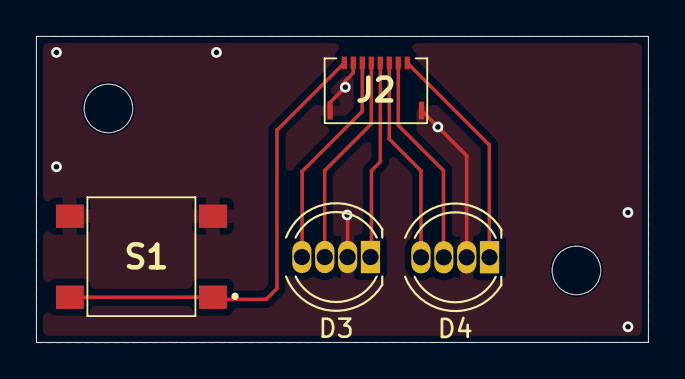
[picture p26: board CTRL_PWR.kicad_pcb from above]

Board: 2 copper layers, 34.0 x 17.0 mm, 6 parts (0 on the bottom side), 8 nets.

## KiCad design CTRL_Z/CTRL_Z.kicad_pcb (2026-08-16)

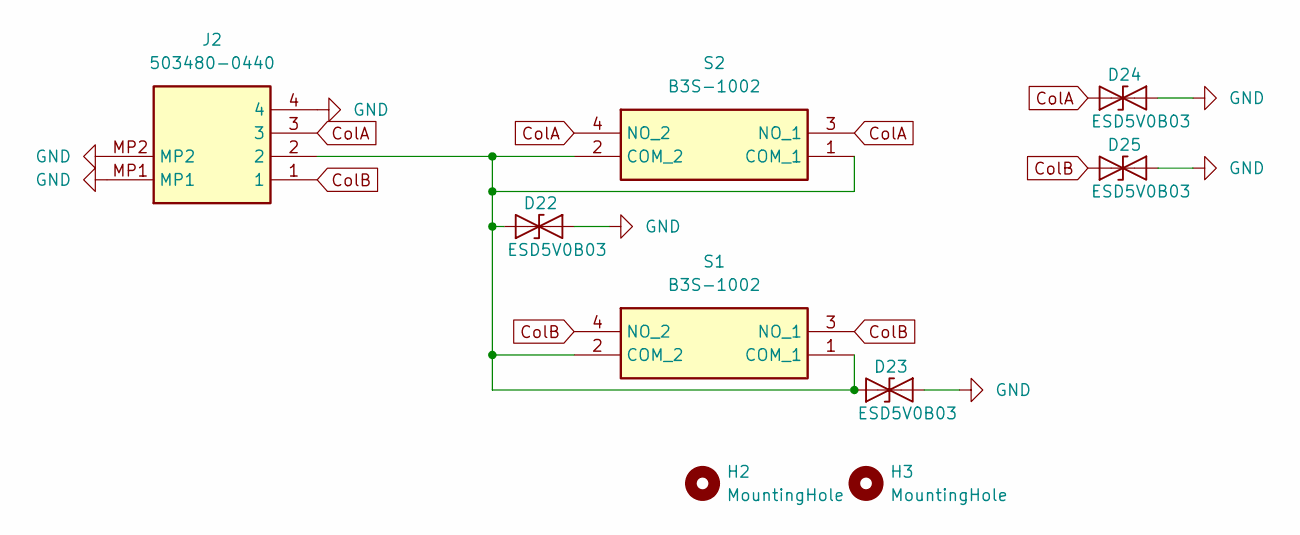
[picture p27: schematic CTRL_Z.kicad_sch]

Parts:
D22, D23, D24, D25: ESD5V0B03; D_0402_1005Metric; MPN ESD5V0B03-1006; LCSC Part C521894
H2, H3: MountingHole; MountingHole_2.5mm; LCSC Part N/A
J2: 503480-0440; 5034800440; Mouser Part Number 538-503480-0440
S1, S2: B3S-1002; B3S1002; Mouser Part Number 653-B3S-1002

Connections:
ColA: D24.2 (A2), J2.3, S2.3 (NO_1), S2.4 (NO_2)
ColB: D25.2 (A2), J2.1, S1.3 (NO_1), S1.4 (NO_2)
GND: D22.1 (A1), D23.1 (A1), D24.1 (A1), D25.1 (A1), J2.4, J2.MP1, J2.MP2
unnamed: D22.2 (A2), D23.2 (A2), J2.2, S1.1 (COM_1), S1.2 (COM_2), S2.1 (COM_1), S2.2 (COM_2)

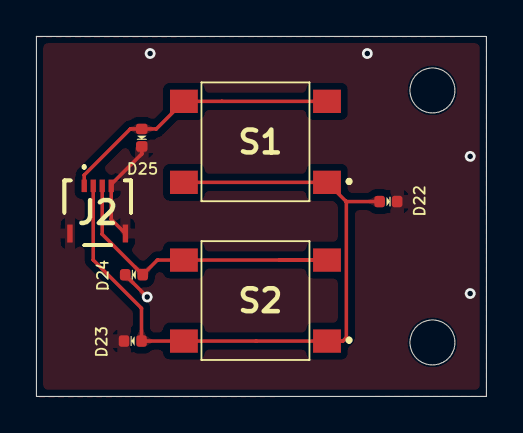
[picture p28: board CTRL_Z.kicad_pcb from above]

Board: 2 copper layers, 25.0 x 20.0 mm, 10 parts (1 on the bottom side), 4 nets.

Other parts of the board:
kibuzzard-6A70E37C: G***; kibuzzard-6A70E37C

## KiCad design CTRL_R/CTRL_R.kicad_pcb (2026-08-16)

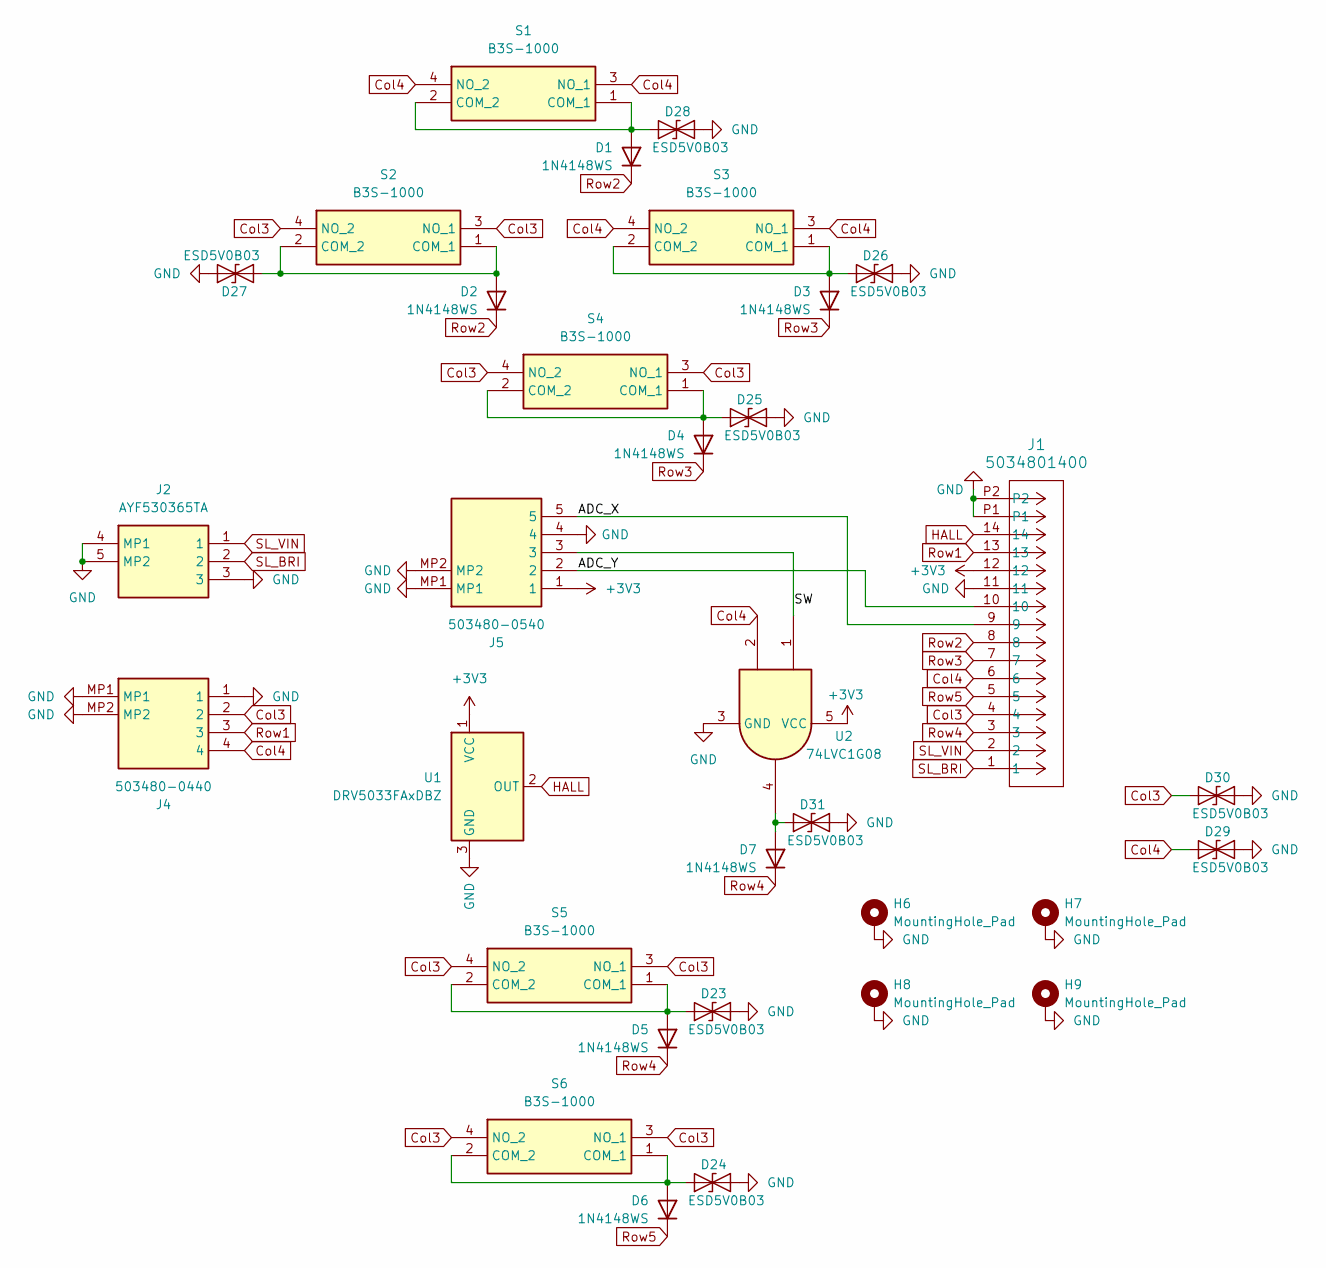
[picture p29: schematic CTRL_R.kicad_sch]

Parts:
D1, D2, D3, D4, D5, D6, D7: 1N4148WS; D_SOD-323; MPN 1N4148WS; LCSC Part C917117
D23, D24, D25, D26, D27, D28, D29, D30, D31: ESD5V0B03; D_0402_1005Metric; MPN ESD5V0B03-1006; LCSC Part C521894
H6, H7, H8, H9: MountingHole_Pad; MountingHole_2.7mm_M2.5_Pad; LCSC Part N/A
J1: 5034801400; MPN 5034801400; LCSC Part C505360
J2: AYF530365TA; AYF530365T; Mouser Part Number 667-AYF530365TA
J4: 503480-0440; 5034800440; Mouser Part Number 538-503480-0440
J5: 503480-0540; 5034800540; Mouser Part Number 538-503480-0540
S1, S2, S3, S4, S5, S6: B3S-1000; B3S1000; Mouser Part Number 653-B3S-1000
U1: DRV5033FAxDBZ; SOT-23; MPN DRV5033FAQDBZR; LCSC Part C2869057
U2: 74LVC1G08; SOT-23-5; MPN 74LVC1G08GV; LCSC Part C53185136

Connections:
+3V3: J1.12, J5.1, U1.1 (VCC), U2.5 (VCC)
/ADC_X: J1.9, J5.5
/ADC_Y: J1.10, J5.2
/SW: J5.3, U2.1
Col3: D30.2 (A2), J1.4, J4.2, S2.3 (NO_1), S2.4 (NO_2), S4.3 (NO_1), S4.4 (NO_2), S5.3 (NO_1), S5.4 (NO_2), S6.3 (NO_1), S6.4 (NO_2)
Col4: D29.2 (A2), J1.6, J4.4, S1.3 (NO_1), S1.4 (NO_2), S3.3 (NO_1), S3.4 (NO_2), U2.2
GND: D23.1 (A1), D24.1 (A1), D25.1 (A1), D26.1 (A1), D27.1 (A1), D28.1 (A1), D29.1 (A1), D30.1 (A1), D31.1 (A1), H6.1 (1_1), H7.1 (1_1), H8.1 (1_1), H9.1 (1_1), J1.11, J1.P1, J1.P2, J2.3, J2.4 (MP1), J2.5 (MP2), J4.1, J4.MP1, J4.MP2, J5.4, J5.MP1, J5.MP2, U1.3 (GND), U2.3 (GND)
HALL: J1.14, U1.2 (OUT)
unnamed: D1.2 (A), D28.2 (A2), S1.1 (COM_1), S1.2 (COM_2)
unnamed: D2.2 (A), D27.2 (A2), S2.1 (COM_1), S2.2 (COM_2)
unnamed: D5.2 (A), D23.2 (A2), S5.1 (COM_1), S5.2 (COM_2)
unnamed: D6.2 (A), D24.2 (A2), S6.1 (COM_1), S6.2 (COM_2)
unnamed: D4.2 (A), D25.2 (A2), S4.1 (COM_1), S4.2 (COM_2)
unnamed: D3.2 (A), D26.2 (A2), S3.1 (COM_1), S3.2 (COM_2)
unnamed: D7.2 (A), D31.2 (A2), U2.4
Row1: J1.13, J4.3
Row2: D1.1 (K), D2.1 (K), J1.8
Row3: D3.1 (K), D4.1 (K), J1.7
Row4: D5.1 (K), D7.1 (K), J1.3
Row5: D6.1 (K), J1.5
SL_BRI: J1.1, J2.2
SL_VIN: J1.2, J2.1

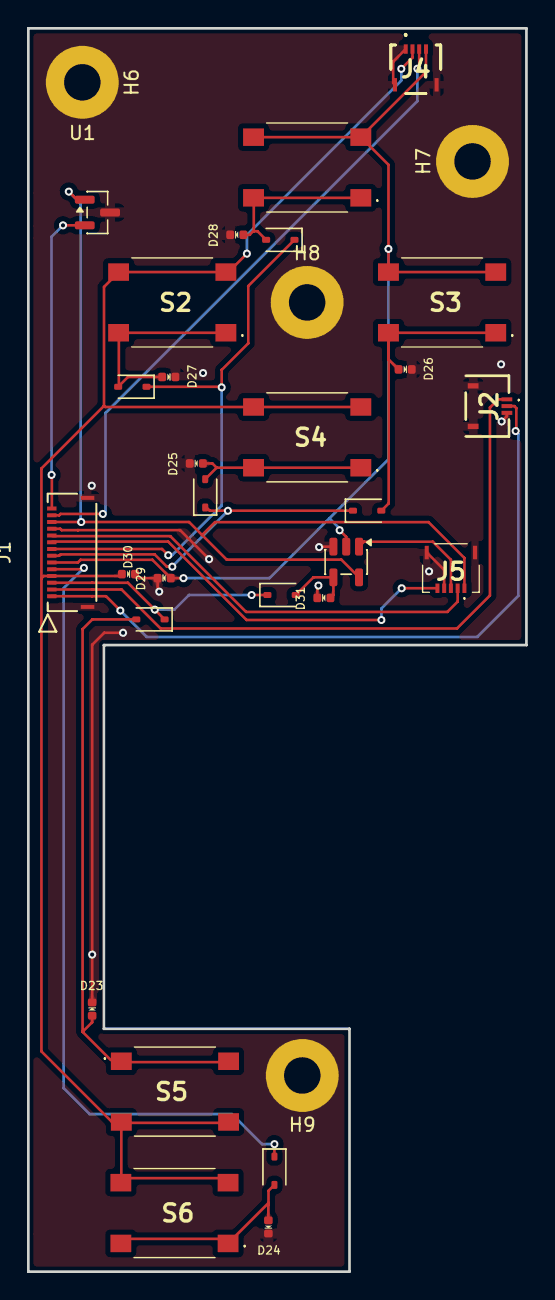
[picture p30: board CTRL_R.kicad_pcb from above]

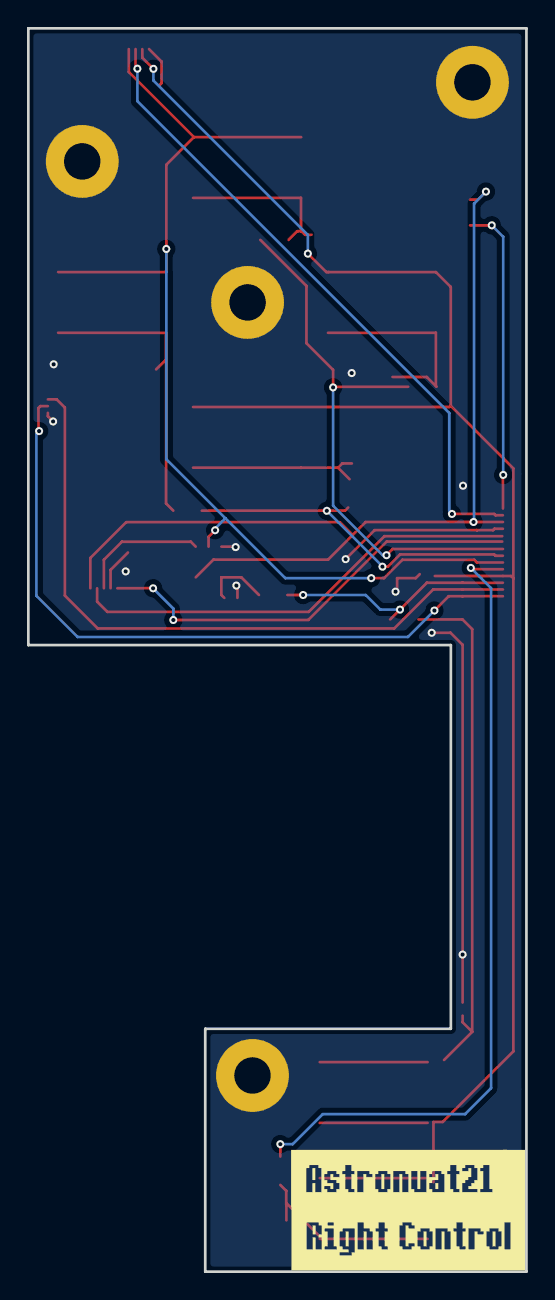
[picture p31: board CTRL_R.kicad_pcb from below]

Board: 2 copper layers, 36.9 x 92.2 mm, 34 parts (2 on the bottom side), 22 nets.

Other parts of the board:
kibuzzard-6A19F3B7: G***; kibuzzard-6A19F3B7
kibuzzard-6A187131: G***; kibuzzard-6A187131

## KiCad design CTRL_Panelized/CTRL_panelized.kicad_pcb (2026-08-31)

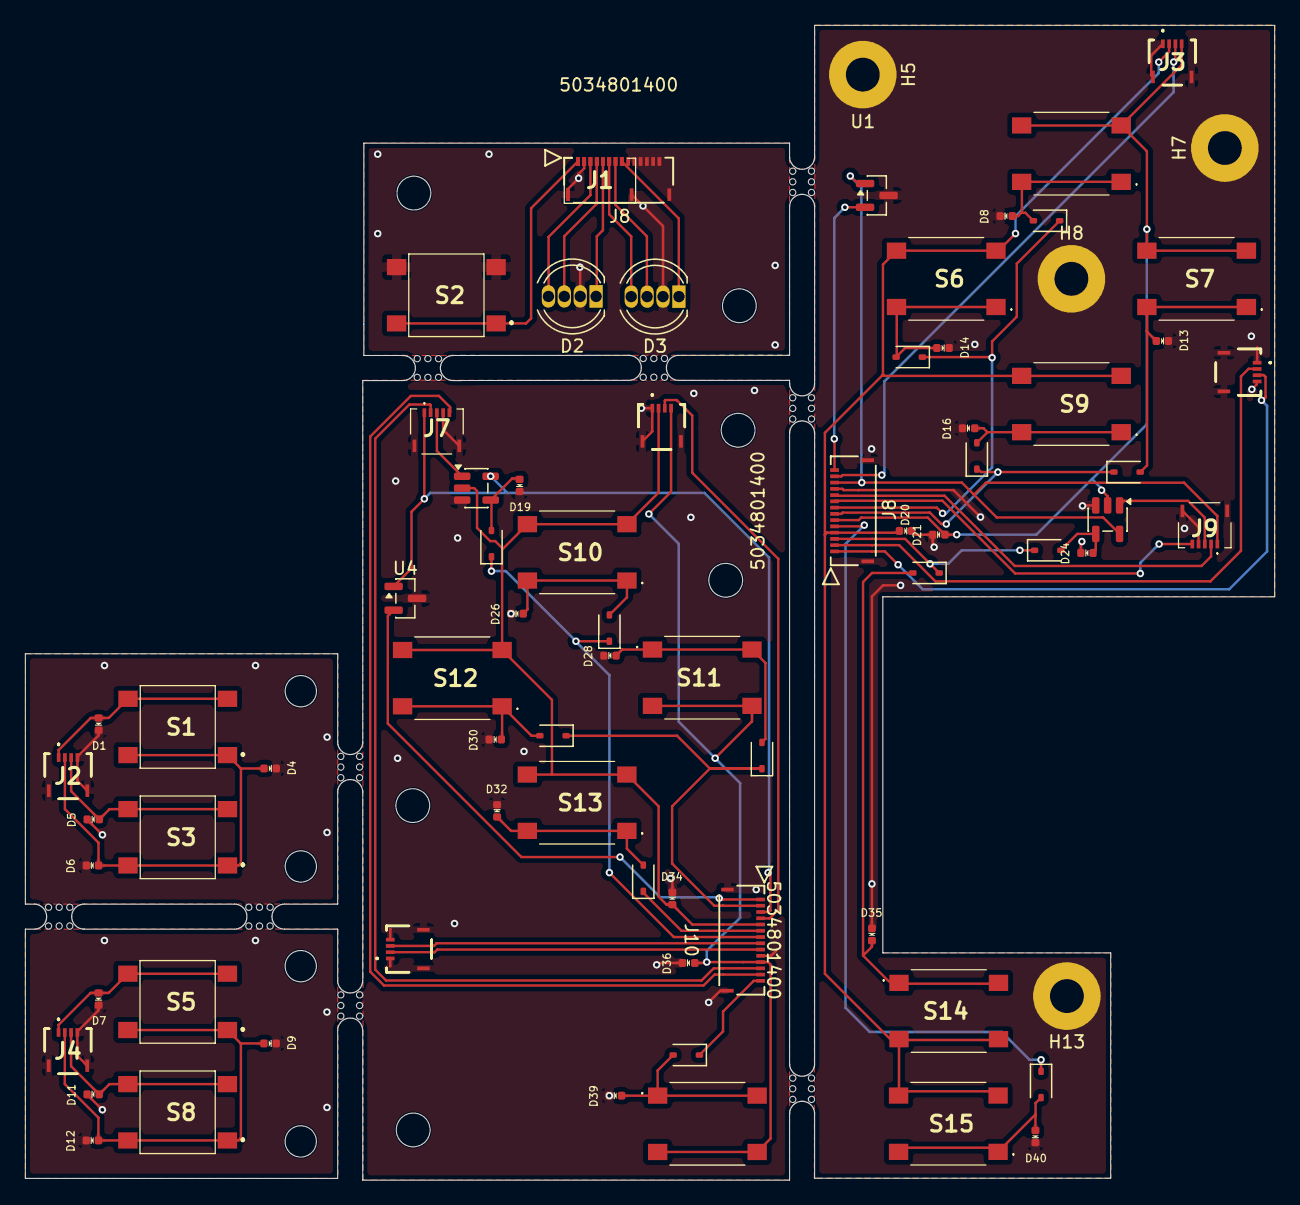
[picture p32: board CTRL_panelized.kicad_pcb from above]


Board: 2 copper layers, 99.8 x 92.2 mm, 92 parts (6 on the bottom side), 36 nets.

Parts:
D1, D4, D5, D6, D7, D8, D9, D11, D12, D13, D14, D16, D19, D20, D21, D24, D26, D28, D30, D32, D34, D35, D36, D39, D40: ESD5V0B03; D_0402_1005Metric
D2, D3: LED_RKGB; LED_D5.0mm-4_RGB
D10, D15, D17, D18, D22, D23, D25, D27, D29, D31, D33, D37, D38: 1N4148WS; D_SOD-323
H1, H3, H10, H11, H12, H14: MountingHole; MountingHole_2.7mm_M2.5
H2, H4, H6, H9: MountingHole; MountingHole_2.5mm
H5, H7, H8, H13: MountingHole_Pad; MountingHole_2.7mm_M2.5_Pad
J1: 503480-0800; 5034800800
J2, J3, J4, J5, J6, J11: 503480-0440; 5034800440
J7, J9: 503480-0540; 5034800540
J8, J8#2, J10: 5034801400
S1, S2, S3, S5, S8: B3S-1002; B3S1002
S4, S6, S7, S9, S10, S11, S12, S13, S14, S15, S16: B3S-1000; B3S1000
U1, U4: DRV5033FAxDBZ; SOT-23
U2, U3: 74LVC1G08; SOT-23-5
kibuzzard-1, kibuzzard-2: G***; kibuzzard-6A70E37C
kibuzzard-3, kibuzzard-6: G***; kibuzzard-6A187131
kibuzzard-4: G***; kibuzzard-6A186FEC
kibuzzard-5: G***; kibuzzard-6A19F3B7

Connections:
+3V3: J7.1, J8#2.12, J9.1, J10.3, U1.1 (VCC), U2.5 (VCC), U3.5 (VCC), U4.1 (VCC)
/ADC_X: J7.5, J8#2.9, J9.5, J10.13
/ADC_Y: J7.2, J8#2.10, J9.2, J10.12
/SW: J7.3, J9.3, U2.1, U3.1
Col1: D34.2 (A2), J6.2, J10.5, S10.3 (NO_1), S10.4 (NO_2), S12.3 (NO_1), S12.4 (NO_2), S13.3 (NO_1), S13.4 (NO_2), U2.2
Col2: D36.2 (A2), J6.4, J10.11, S11.3 (NO_1), S11.4 (NO_2), S16.3 (NO_1), S16.4 (NO_2)
Col3: D20.2 (A2), J3.2, J8#2.4, S6.3 (NO_1), S6.4 (NO_2), S9.3 (NO_1), S9.4 (NO_2), S14.3 (NO_1), S14.4 (NO_2), S15.3 (NO_1), S15.4 (NO_2)
Col4: D21.2 (A2), J3.4, J8#2.6, S4.3 (NO_1), S4.4 (NO_2), S7.3 (NO_1), S7.4 (NO_2), U3.2
ColA: D5.2 (A2), D11.2 (A2), J2.3, J4.3, S3.3 (NO_1), S3.4 (NO_2), S8.3 (NO_1), S8.4 (NO_2)
ColB: D1.2 (A2), D7.2 (A2), J2.1, J4.1, S1.3 (NO_1), S1.4 (NO_2), S5.3 (NO_1), S5.4 (NO_2)
GND: D1.1 (A1), D2.2 (K), D3.2 (K), D4.1 (A1), D5.1 (A1), D6.1 (A1), D7.1 (A1), D8.1 (A1), D9.1 (A1), D11.1 (A1), D12.1 (A1), D13.1 (A1), D14.1 (A1), D16.1 (A1), D19.1 (A1), D20.1 (A1), D21.1 (A1), D24.1 (A1), D26.1 (A1), D28.1 (A1), D30.1 (A1), D32.1 (A1), D34.1 (A1), D35.1 (A1), D36.1 (A1), D39.1 (A1), D40.1 (A1), H5.1 (1_1), H7.1 (1_1), H8.1 (1_1), H13.1 (1_1), J1.2, J1.9, J1.10, J2.4, J2.MP1, J2.MP2, J3.1, J3.MP1, J3.MP2, J4.4, J4.MP1, J4.MP2, J5.1, J5.4, J5.MP1, J5.MP2, J6.1, J6.MP1, J6.MP2, J7.4, J7.MP1, J7.MP2, J8#2.11, J8#2.P1, J8#2.P2, J9.4, J9.MP1, J9.MP2, J10.10, J10.P1, J10.P2, J11.1, J11.4, J11.MP1, J11.MP2, S2.3 (NO_1), S2.4 (NO_2), U1.3 (GND), U2.3 (GND), U3.3 (GND), U4.3 (GND)
HALL: J8#2.14, J10.1, U1.2 (OUT), U4.2 (OUT)
unnamed: D8.2 (A2), D10.2 (A), S4.1 (COM_1), S4.2 (COM_2)
unnamed: D14.2 (A2), D15.2 (A), S6.1 (COM_1), S6.2 (COM_2)
unnamed: D2.4 (BA), J1.3
unnamed: D2.3 (GA), J1.4
unnamed: D2.1 (RA), J1.5
unnamed: D3.4 (BA), J1.6
unnamed: D3.3 (GA), J1.7
unnamed: D3.1 (RA), J1.8
unnamed: D4.2 (A2), D6.2 (A2), D9.2 (A2), D12.2 (A2), D26.2 (A2), D27.2 (A), J2.2, J4.2, S1.1 (COM_1), S1.2 (COM_2), S3.1 (COM_1), S3.2 (COM_2), S5.1 (COM_1), S5.2 (COM_2), S8.1 (COM_1), S8.2 (COM_2), S10.1 (COM_1), S10.2 (COM_2)
unnamed: D25.2 (A), D29.2 (A), D30.2 (A2), D35.2 (A2), S12.1 (COM_1), S12.2 (COM_2), S14.1 (COM_1), S14.2 (COM_2)
unnamed: D28.2 (A2), D31.2 (A), D38.2 (A), D40.2 (A2), S11.1 (COM_1), S11.2 (COM_2), S15.1 (COM_1), S15.2 (COM_2)
unnamed: D16.2 (A2), D17.2 (A), D32.2 (A2), D33.2 (A), S9.1 (COM_1), S9.2 (COM_2), S13.1 (COM_1), S13.2 (COM_2)
unnamed: D13.2 (A2), D18.2 (A), D37.2 (A), D39.2 (A2), S7.1 (COM_1), S7.2 (COM_2), S16.1 (COM_1), S16.2 (COM_2)
unnamed: D19.2 (A2), D22.2 (A), U2.4
unnamed: D23.2 (A), D24.2 (A2), U3.4
unnamed: J1.1, S2.1 (COM_1), S2.2 (COM_2)
Row1: J3.3, J6.3, J8#2.13, J10.4
Row2: D10.1 (K), D15.1 (K), D22.1 (K), D27.1 (K), J8#2.8, J10.7
Row3: D17.1 (K), D18.1 (K), D29.1 (K), D31.1 (K), J8#2.7, J10.2
Row4: D23.1 (K), D25.1 (K), D33.1 (K), J8#2.3, J10.6
Row5: D37.1 (K), D38.1 (K), J8#2.5, J10.14
SL_BRI: J5.3, J8#2.1
SL_VIN: J5.2, J8#2.2, J10.9, J11.2
SL_VOL: J10.8, J11.3

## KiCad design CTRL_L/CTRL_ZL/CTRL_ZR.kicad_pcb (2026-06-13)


Board: 2 copper layers, 34.0 x 17.0 mm, 8 parts (1 on the bottom side), 9 nets.

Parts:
D1: LED_PWR; LED_D5.0mm-4_RGB
D2: LED_WIFI; LED_D5.0mm-4_RGB
H1, H2: MountingHole; MountingHole_2.7mm_M2.5
J1: BM09B-NSHSS-TBT_LF__SN_; BM09BNSHSSTBTLFSN
S1: B3S-1002; B3S1002
kibuzzard-6A2CA9F9: G***; kibuzzard-6A2CA9F9
kibuzzard-6A2CAA19: G***; kibuzzard-6A2CAA19

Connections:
+3V3: J1.2, S1.3 (NO_1), S1.4 (NO_2)
GND: D1.3 (K), D2.3 (K), J1.6, J1.MP1, J1.MP2
unnamed: D1.1 (BA), J1.5
unnamed: D1.2 (GA), J1.4
unnamed: D1.4 (RA), J1.3
unnamed: D2.1 (BA), J1.7
unnamed: D2.2 (GA), J1.8
unnamed: D2.4 (RA), J1.9
unnamed: J1.1, S1.1 (COM_1), S1.2 (COM_2)

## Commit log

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2026-05-12 Fixed M.2 Connector Setup
    [Mainboard.kicad_pcb, Mainboard.kicad_sch]
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2026-05-15 Switch to 4-Layer Setup: F.Cu, In.GND, In.PWR, B.Cu
    [Mainboard.kicad_pcb]
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2026-05-22 Joystick Update!
    (Credits to dbenoy for the footprint)
    https://github.com/dbenoy/thumbstick-breakout
    [CTRL_L.kicad_pcb, CTRL_L.kicad_sch]
2026-05-22 PCB Wiring Complete*
    Updated to JST NSH connector.
    L,XL/Sliders TB moved to another PCB.
    [CTRL_L.kicad_pcb, CTRL_L.kicad_sch]
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2026-05-26 Added kinda broken Left Sliders
    [CTRL_L_SLIDERS.kicad_pcb, CTRL_L_SLIDERS.kicad_sch]
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2026-05-28 Left Controls Complete* *Omron Switches to be changed
    [CTRL_L.kicad_sch]
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2026-05-31 Removed the test points because i dont know what im doing.
    [CTRL_L_SLIDERS.kicad_pcb, CTRL_L_SLIDERS.kicad_sch, CTRL_R.kicad_pcb]
2026-06-07 Add LattePandaMu Board files, many fixes to do!
    [CTRL_L_SLIDERS.kicad_pcb, CTRL_L_SLIDERS.kicad_sch, GPIO.kicad_sch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]
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2026-06-10 Mainboard Progress, Updated CTRL-L for new Joystick Module
    [CTRL_L.kicad_pcb, CTRL_L.kicad_sch, HDMI.kicad_sch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]
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2026-06-11 Fixed 3D Model associations on CTRL_L and CTRL_R
    [CTRL_L.kicad_pcb, CTRL_R.kicad_pcb]
2026-06-12 Created CTRL_R_PWR Placeholder files
    Also removed unnecessary "PWR_Button" Global Label in CTRL_R
    [3W_Speakers.3mf, 3W_Speakers.stl, 4DS Shell test 175x95x30 +2.5S F=7 B=5 .3mf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]
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2026-06-24 CTRL_Z added, replacement of ZL/ZR
    - The X and ZX shoulder buttons now designed in a vertical only layout akin to joysticks.
    This removes the need for seperate ZL / ZR PCBs. CTRL_Z as a consequence has differing global labels because of the ambiguity.
    This change in design is helpful due to the (5x minimum) nature of ordering PCBs.
    [3W_Speakers.3mf, CTRL_Z.kicad_pcb, CTRL_Z.kicad_sch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]
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2026-06-27 "Scrapped" the current Mainboard, seems to be very broken for no reason.
    It is being kept for now so that work done for the displays can be copied over later.
    [GPIO.kicad_sch, HDMI.kicad_sch, LattePanda Module.kicad_sch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]
2026-06-29 Attempt 3 of the Mainboard. Display-out fully wired
    [FIT0981_Active_cooler.STEP, GPIO.kicad_sch, Gigabit Ethernet.kicad_sch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]
2026-06-29 Renamed "Mainboard" to "Motherboard"
    idk why it wasnt like that before.
    [GPIO.kicad_sch, HDMI.kicad_sch, LattePanda Module.kicad_sch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]
2026-07-02 Updated M key to be strictly SSD (no SATA)
    [M.2 E&M Key.kicad_sch]
2026-07-03 Gave each screen a seperate backlight controller (different nit brightness)
    [HDMI.kicad_sch, LattePanda_Mu_Dimension_Drawing.dxf, fan_temp.kicad_sch]
2026-07-04 Switched Template Carrier board due to issues with the Lattepanda-provided version.
    I am not sure what the cause of these "A:DFRobot" missing library footprints are, however the carrier board designed by
    youtuber "Ben Makes Everything" has no large changes to the schematic files that I cant handle, and dosen't have this annoying issue. For this reason I
    will be using his design as a base. Although I am not using his design directly, I will still link his repository:
    https://github.com/BenMakesEverything/Mu_Cyberdeck/tree/main
    Thank you BenMakesEverything!
    [2086581001.step, 2086581001.stp, 48406-0001.stp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]
2026-07-04 Slight Schematic fixes. Motherboard.RADXA removed from the codebase (Useless now) (Previous Commit change)
    [Mu-cyberdeck-carrier.kicad_sch, [DFR1142]Lite Carrier for LattePanda Mu(V2).kicad_sch]
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2026-07-07 CTRL Z, R, PWR Cleanup! Changes Made:
    CTRL PWR -> Added Ground Plane and Ground Vias. Moved it out of parent folder CTRL_R upto Root.
    CTRL Z -> Removed Unnecessary ZX pin. Added Ground Plane and Ground Vias.
    CTRL R -> Cleaned up pin count, from 14 down to 10. Added Ground Plane and Ground Vias. Made some modifications to the board shape.
    [CTRL_PWR.kicad_pcb, CTRL_PWR.kicad_sch, CTRL_R.kicad_pcb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]
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2026-07-07 Renamed some things / Removed borked Motherboard design
    [2086581001.step, 2086581001.stp, 48406-0001.stp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]
2026-07-08 CTRL_L Cleanup: Reduced 14 to 12 pins, added Ground Planes and Vias, and general wiring cleanups
    [CTRL_L.kicad_pcb, CTRL_L.kicad_sch, GPIO.kicad_sch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]
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2026-07-08 Added RP2040 MCU, Handles all External IO Systems (Except Audio), WIP.
    [CTRL_L_SLI.kicad_pcb, CTRL_L_SLI.kicad_sch, GPIO.kicad_sch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]
2026-07-09 Added stereo Audio using CP2615 > PCM5102A > PAM8403D through USB (Mu has dysfunctional I2S)
    [HDMI.kicad_sch, LattePanda Module.kicad_sch, PSU.kicad_sch]
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2026-07-15 Switched Screens to use RGB interface, ADV7613 -> ADV7611. Changes WIP
    [HDMI.kicad_sch, LattePanda Module.kicad_sch, Motherboard.kicad_sch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]
2026-07-15 Switched HDMI DBUG and TCP0 back, added I2C Protection circuits, and a lot more random changes/updates/progress
    [HDMI.kicad_sch, LattePanda Module.kicad_sch, Motherboard.kicad_pcb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]
2026-07-16 Partial wiring of power path and top screen
    [HDMI.kicad_sch, Motherboard.kicad_pcb, Motherboard.kicad_sch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]
2026-07-16 Wired PSU (May need to be edited, Screen connector location needs to be verified)
    [PSU.kicad_sch]
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2026-07-21 Rewired M.2 M key to fit new location. removed Fan_Temp as the design will move to a passive heatsink.
    [HDMI.kicad_sch, LattePanda Module.kicad_sch, Motherboard.kicad_pcb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]
2026-07-22 Moved 3V3 and 5V converters to better fit the layout. Began Wiring for DDIB. Partially rewired TCP0 due to a schematic mistake.
    [HDMI.kicad_sch, LattePanda Module.kicad_sch, Motherboard.kicad_pcb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]
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2026-07-25 Corrected CTRL_PWR (+other WIP changes)
    [CTRL_L.kicad_pcb, CTRL_L.kicad_sch, CTRL_PWR.kicad_sch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]
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2026-07-26 Updated CTRL_Z to use 3 pin FPC and ESD Protection.
    [CTRL_PWR.kicad_pcb, CTRL_PWR.kicad_sch, CTRL_R.kicad_pcb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]
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2026-07-26 Updated CTRL_L to use FPC connectors, single volume slider, extra connector for CTRL_Z and added ESD Diodes.
    [CTRL_L.kicad_pcb, CTRL_L.kicad_sch, CTRL_L.v1_bom.csv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]
2026-07-27 Updated CTRL_R to have ESD diodes, CTRL_Z connector, FPC, yada yada.
    Its the same stuff as the commit with CTRL_L.
    [CTRL_R.kicad_pcb, CTRL_R.kicad_sch]
2026-07-27 Old Motherboard version removed from the repo; as it is now sufficiently outdated.
    [FIT0981_Active_cooler.STEP, GPIO.kicad_sch, Gigabit Ethernet.kicad_sch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]
2026-07-28 Removed CTRL_L_SLI as it is no longer used. Switched MCU from RP2040 to RP2354B, for the added ADC inputs.
    [CTRL_L_SLI.kicad_pcb, CTRL_L_SLI.kicad_sch, HDMI.kicad_sch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]
2026-08-01 Many, Many fixes and changes. Mostly Schematic-related.
    [HDMI.kicad_sch, LattePanda Module.kicad_sch, Motherboard.kicad_pcb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]
2026-08-03 Quick Save: Many things are being changed/updated/fixed.
    [GPIO.kicad_sch, HDMI.kicad_sch, LattePanda Module.kicad_sch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]
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2026-08-03 Updated CTRL_L to use 4 pin FPC (3 pin is hard to source!)
    [CTRL_L.kicad_pcb, CTRL_L.kicad_sch, CTRL_Z.kicad_pcb]
2026-08-03 Updated CTRL_R to use 4 pin FPC and fixed DRC errors.
    [CTRL_R.kicad_pcb, CTRL_R.kicad_sch]
2026-08-05 Multiplexed Debug HDMI port with DDIB screen, there are no BIOS versions with HDMI out on TCP1.
    [CTRL_R.kicad_sch, HDMI.kicad_sch, LattePanda Module.kicad_sch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]
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2026-08-06 Re-Routed DDIB Screen, pinout was previously flipped
    [HDMI.kicad_sch, LattePanda Module.kicad_sch, Motherboard.kicad_pcb]
2026-08-07 Re-Routed top screen <-> ADV7611, with varying success
    [HDMI.kicad_sch, Motherboard.kicad_pcb, PSU.kicad_sch]
2026-08-08 Various fixes, and some peripheral routing
    [GPIO.kicad_sch, HDMI.kicad_sch, LattePanda Module.kicad_sch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]
2026-08-08 Updated CTRLs to be one sided (saves a billion dollars somehow), added LCSC_Parts for BOM, and other fixes. (Part 1/2)
    [CTRL_L.kicad_pcb, CTRL_L.kicad_sch, CTRL_L.v1.1_bom.csv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]
2026-08-09 Updated CTRL_L and R to fit new CTRL_Z connector placement
    [CTRL_L.kicad_pcb, CTRL_L.v2.2_bom.csv, CTRL_L.v2.2_designators.csv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]
2026-08-10 Completed routing of 9V and 3.3V of PSU
    [CTRL_PWR.kicad_pcb, CTRL_PWR.kicad_sch, CTRL_PWR.v3_bom.csv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]
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2026-08-11 Swapped Volume and Brightness sliders for easier wiring.
    [GPIO.kicad_sch, LattePanda Module.kicad_sch, Motherboard.kicad_pcb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]
2026-08-13 Routed RP2354B, USB ports, rewired HDMI lanes to be cleaner, and many other fixes and improvements.
    [GPIO.kicad_sch, HDMI.kicad_sch, LattePanda Module.kicad_sch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]
2026-08-15 Created updated BOM for PCBWay on all CTRL daughterboards. These boards have likely hit their final* version
    *Ive said "Finished Version" many times in this project. I'm confident now, but no guarantees.
    [CTRL_L.kicad_sch, CTRL_L.v2.3_bom.csv, CTRL_L.v2.3_designators.csv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]
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2026-08-23 Some fixes and stuff. i guess.
    [CTRL_PANEL.BOM.csv, CTRL_PANEL.v2_bom.csv, CTRL_PANEL.v2_designators.csv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]
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2026-08-25 Fixed 3DS Volume slider connector (3 -> 4pin)*
    *Changed only in CTRL_Panelized. Seperated PCBs will be updated once all changes are done.
    [CTRL_PANEL.BOM.csv, CTRL_PANEL.v3_bom.csv, CTRL_PANEL.v3_designators.csv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]
2026-08-31 Majorly reworked Display system, condensed and fixed BOM, and many other schematic and design cleanups. \Programs folder was also cleaned up.
    Everything is still a work in progress, many things are now unfinished, especially the PCB.
    [CTRL_PANEL.BOM_v3.csv, CTRL_panelized.kicad_pcb, GPIO.kicad_sch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]
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2026-10-24 Performed analysis of current work. Documented motherboard issues, new revision Todo
    - Also updated README
    - Other stuff
    - 3D Modeling in progress
    - Nothing significant done, just want to break the lack of updates.
    Project aim to finish before 2027, otherwise no further deadline will be set.
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
